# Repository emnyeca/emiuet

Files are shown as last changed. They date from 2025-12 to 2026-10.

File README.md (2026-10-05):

# Emiuet (EUB-04)

<p align="center">
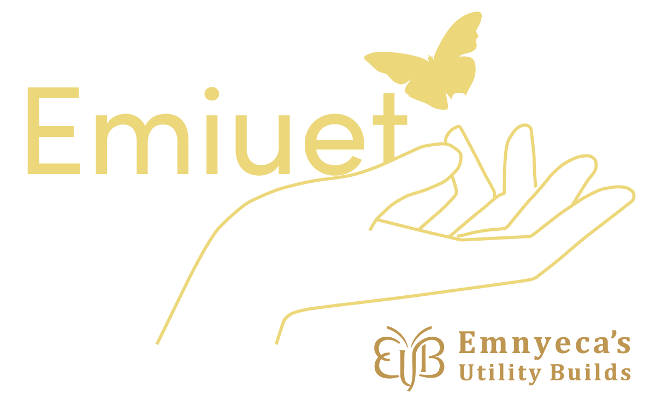
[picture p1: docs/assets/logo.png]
Emiuet logo
  
</p>

Fretboard-style MIDI instrument for guitarists.

## What Emiuet is

**Emiuet** is a 6 × 13 fretboard MIDI controller built around the way guitarists
think: strings, fret positions, chord shapes, voicings, and controlled expressive
gestures. It is not intended to become a general-purpose pad controller or a
piano-style keyboard.

The thirteen positions preserve familiar guitar-derived voicings without forcing
octave shifts or omissions. Expressive controls are deliberately constrained so
that performance remains predictable: Pitch Bend is upward-only, and the optional
MPE-style mode separates strings by MIDI channel rather than attempting a fully
general per-note control system.

Emiuet is part of **Emnyeca's Utility Build Series (EUB)**. The project prioritizes
musical intent, reliability, and a clear physical mental model over feature breadth.

## Playing surface and controls

- 6 strings × 13 positions: 78 low-profile keys
- Three sliders: Velocity, CC#1 Modulation, and upward-only Pitch Bend
- Constrained stringwise MPE-style performance mode
- Minimal OLED feedback designed to avoid distracting from performance
- USB MIDI, Type-A TRS MIDI OUT/IN, and BLE capability
- Auxiliary USB HID Keyboard mode (`TYPE`)
- One RGB LED under each key for fretboard visualization

`TYPE` is a desk-convenience feature for short text, navigation, and shortcuts.
It reuses the physical matrix but does not change Emiuet's identity as a musical
instrument. See [USB HID Keyboard Mode](docs/keyboard-mode.md) for the complete
layout and Fn layer.

## Rev.B hardware summary

Rev.B simplifies Emiuet into a USB-powered Device/UFP:

- ESP32-S3-MINI-1 using native USB
- One USB-C port for 5 V power, USB MIDI, USB HID, and firmware flashing
- Persistent USB MIDI + HID Keyboard composite device
- USB-C CC pull-downs with a comparator that tracks the Source current advertisement
- No USB Host, DRP, Host VBUS sourcing, internal battery, charger, or PowerPath
- SK6812 MINI-E ×78 on one data chain with a 3.3 V-to-5 V buffer
- Firmware-limited LED brightness/current based on conservative USB power budgets

Mobile use is supported with an external USB power bank. A 3 A Source advertisement
does not raise Emiuet's internal design ceiling above approximately 5 V / 1.5 A.

## MIDI and RGB behavior

Performance logic remains independent of individual transports. MIDI generation
must not block on USB, TRS, or BLE output. Incoming USB or TRS Note On/Off messages
can drive fretboard visualization through a transport-independent LED state layer.

The external protocol for device-level LED settings such as global brightness is
not defined yet. Standard musical Control Change messages are not repurposed for
device configuration; a future explicit protocol may use SysEx.

## Hardware and firmware sources

- Current Rev.B schematic draft: `hardware/kicad/Emiuet.kicad_sch`
- Historical Rev.A schematic: `hardware/kicad/Emiuet_RevA.kicad_sch`
- Rev.B GPIO allocation: `docs/pinout-v3.md`
- Current design decisions: `docs/decisions.md`
- Firmware: ESP-IDF 5.3.4 + FreeRTOS; OLED rendering uses u8g2

The checked-in PCB layout is historical Rev.A data and was not updated with the
Rev.B schematic. Rev.B placement and routing require a separate PCB redesign.

## Project status

The Rev.B schematic is an early architecture draft, not a fabrication-ready release.
USB-C current detection, reset/boot, the RGB buffer, and the OLED connector are
drawn; power and MIDI circuits are incomplete, and the matrix, sliders, buttons,
and protection circuits still need implementation. Component selection, footprints, PCB layout,
and physical validation remain open engineering work.

## License

To be determined. An open-source-friendly license is planned after prototype
validation.

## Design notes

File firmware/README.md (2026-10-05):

# Emiuet Rev.B firmware

ESP-IDF 5.3.4、ESP32-S3-MINI-1-N4R2向けです。

## Data paths

```text
matrix → input_router → USB/TRS MIDI TX or USB HID
USB MIDI RX / isolated TRS MIDI RX → midi_input → led_control
→ led_renderer → espressif/led_strip RMT DMA → SK6812 x78
CC comparator (GPIO37) → usb_cc_detect → usb_power → renderer current limiter / OLED status
```

USBはbus-powered Composite Deviceです。self-powered VBUS GPIO、Host stack、role
negotiation、battery/charger stateはありません。

初期RGB inputはMIDI Note On/OffとCC123 All Notes Offです。global brightnessを含む
device-level LED control protocolは未確定です。CC7などのstandard musical CCを
device configurationへ転用せず、将来SysEx等の明示的なprotocolとして定義します。
SysEx拡張点はtransportの外側に残していますが、protocolはまだ固定しません。

## Build

ESP-IDF shellで次を実行します。

```text
idf.py -B build-revb -D SDKCONFIG=build-revb/sdkconfig \
  -D SDKCONFIG_DEFAULTS="sdkconfig.defaults;sdkconfig.rev-b.defaults" build
```

FreeRTOS tickは1000 Hz（`CONFIG_FREERTOS_HZ=1000`）を前提にしています。100 Hzでは `pdMS_TO_TICKS(1)` と `pdMS_TO_TICKS(5)` が0になり、matrix scanは最小1 tick補正で10 ms周期、補正のない再送待ちは待機なしになっていたためです。既存のbuild用sdkconfigはdefaultsで上書きされないので、古い値のままだと `matrix_scan.c` がbuildを止めます。その場合はbuild directoryの `sdkconfig` の該当行を直すか、`sdkconfig` を退避して再生成してください。

MIDI送信task（USB/TRS/BLE）は、producerからのtask notificationで起きて、queueとcoalesce値を出し切ってから待ちます。演奏側は待ちなしでenqueueし、通知するだけです。

`espressif/led_strip`はRMT backendとESP32-S3 DMAを使用します。`sdkconfig.defaults`の
Default/1.5A LED budgetとbrightness ceilingはVAL-CORE-01/V3実測後に確定します。

Host-side logic testsは `tests/` にあります。ESP-IDF buildがUSB descriptor、I2C、
UART、RMTを含むintegration checkです。

## Rev.B設計中の電力制御

起動直後のCC判定前はRGB budgetを0にします。Default広告ではUSB configuredかつ非suspendの場合だけ200 mA設定を許可し、Rp ≥ 1.5 A（3 Aを含む）では1000 mA設定を上限とします。これはLEDの推定予算であり、基板全体のUSB消費電流保証ではありません。

`usb_cc_detect` は10 ms周期でGPIO37を読み、Rp低下は2 sample、上昇は100 ms安定で反映します。Type-C tSinkAdj（60 ms）内に収める設計ですが、実機の応答時間測定は未完了です。根拠・次の作業は [回路ノート](../docs/rev-b-circuit-notes.md) と [ロードマップ](../docs/rev-b-roadmap.md) を参照してください。

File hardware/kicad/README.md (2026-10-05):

# KiCad sourceの位置づけ

- `Emiuet.kicad_sch`: 現行Rev.B schematic architecture draft（KiCad 10形式）
- `Emiuet_RevA.kicad_sch`: Rev.A historical schematic
- `Emiuet.kicad_pcb`: Rev.A historical PCB layout。今回のRev.B作業では未変更

Rev.B schematicとRev.A PCBはconnectivityが一致しません。historical boardに対してschematicからPCB updateを実行しないでください。Rev.B placement/routingは別のPCB redesignとして行います。

Rev.B draftではsingle USB-C UFP/power path、CC Rd＋comparatorによる電流広告検出、ESP32-S3 GPIO nets、3.3 V regulator候補、RGB level shifter、78-pixel serpentine data chain、bulk/local bypass方針、TRS MIDI IN/OUT、OLED connector、matrix/UI busesを確認できます。

これはproduction releaseではありません。reset/BOOT、CC検出、RGB bufferの電源接続とidle bias、OLED connectorを実回路化しました。regulatorとMIDI interfaceは未接続で、matrix/slider/button、input protection、各LEDのlocal bypass等は実回路化が必要です。component selection、footprints、接続設計、ERC確認と実機Validationを経て確定します。

OLED footprint `Eminuet Library:Waveshare_OLED_0.96in_C_7P` はRev.A PCBのBrd2（`EUB_SSD1306:9E6018AD`、B面・180°配置）から形状を変えずに書き出したものです。旧名・説明のAdafruit 1.3 inchは実物と異なります。

初期の実ファイル検証と再設計・EDA評価の記録は [Rev.B監査](../../docs/rev-b-audit.md) にあります（監査時点の状態）。

現在の進捗・再開手順は [ロードマップ](../../docs/rev-b-roadmap.md)、追加回路の根拠と機構条件は [回路ノート](../../docs/rev-b-circuit-notes.md) にあります。`python tools/verify_hardware.py` をリポジトリrootから実行すると、KiCad 10.0.3でERC/netlist/BOM/SVGと入力hashを `build/hardware/` に出力します。違反が残る現状では終了コード1が正常な検出結果です。出力BOMはレビュー用で、発注用ではありません。

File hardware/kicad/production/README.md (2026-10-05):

# Rev.A historical production outputs

このdirectoryと既存の`Emiuet.kicad_pcb`はRev.A/historical design stateに属します。BQ24074、internal battery、boost、PowerPath、dual USB、Host VBUSの記述は現行Rev.B requirementではありません。

Rev.B schematicからこれらのoutputを再生成しないでください。schematic review後にRev.B用のplacement/routingを別工程として行い、production outputsを作り直します。

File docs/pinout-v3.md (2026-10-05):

# Emiuet Rev.B GPIO allocation

この表がRev.B schematicとfirmwareのGPIO正本です。ESP32-S3-MINI-1-N4R2を前提とし、
GPIO26は内蔵PSRAM用として使いません。

| Function | GPIO | Module pin | Reason |
|---|---:|---:|---|
| Slider PB / MOD / VEL | 1 / 2 / 4 | 5 / 6 / 8 | ADC1 CH0/1/3。USBやradioと競合しにくい連続群 |
| Matrix rows 0–5 | 5–10 | 9–14 | 6本連続でstring方向をescapeしやすい |
| Matrix cols 0–7 | 11–18 | 15–22 | 8本連続 |
| USB D- / D+ | 19 / 20 | 23 / 24 | native USB固定 |
| Matrix col 8 | 21 | 25 | USB pair直後の残り1本 |
| Matrix cols 9–12 | 33–36 | 28 / 29 / 31 / 32 | 4本連続。使用module variantでavailabilityを再確認 |
| USB_CC_1A5_N | 37 | 33 | CC comparatorのopen-drain出力（Low = Rp ≥ 1.5 A）、外部pull-up |
| SK6812 DATA | 38 | 34 | RMT TX → AHCT buffer |
| I2C SDA / SCL | 39 / 40 | 35 / 36 | OLED (0x3C) |
| SW CENTER / RIGHT | 41 / 42 | 37 / 38 | active-low button inputs |
| TRS MIDI OUT / IN | 43 / 44 | 39 / 40 | UART1 TX/RXをGPIO matrixで割当 |
| SW LEFT | 47 | 27 | active-low button input |
| Pilot LED | 48 | 30 | status output |

## Reserved and spare

| GPIO | Treatment |
|---:|---|
| 0 | BOOT/download button専用。通常機能へ共用しない |
| 3 | strapping。spare test pad候補だがreset中は外部駆動禁止 |
| 26 | N4R2 embedded PSRAM。使用禁止 |
| 45 / 46 | strapping。spare test pad候補だが量産機能へ割当しない |

GPIO3/45/46は「空き」ではありますが、安全な汎用spareとは扱いません。GPIO0を含む
4本はboot/recoveryを優先します。GPIO19/20にはLED、UART、matrixを重ねません。

## Routing intent

行列は5–18、21、33–36へまとめ、MCUからkey fieldへ束として出します。USB pairは
19/20からconnectorへ最短・等長で配線し、matrixから離します。ADC1の1/2/4は
slider RC filterへ短く配線します。RGB dataは38からbuffer、series resistor、D1へ
進み、5V power returnとは平行長距離にしません。UART43/44はTRS edge側へ一組で出します。

旧GPIO表、BAT_VSENSE、CHG、PGOOD、GPIO42 VBUS monitorはRev.A/撤回案です。

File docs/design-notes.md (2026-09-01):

# Emiuet – Design Notes

This document records design rationale, constraints, and implementation intent
that are intentionally omitted from the README.

It exists to preserve musical and engineering intent across revisions,
contributors, and AI-assisted development.

This is not a user manual.

---

## 1. Overall System Intent

Emiuet is designed as a performance instrument, not a development board.

Design decisions prioritize:
- Stable behavior during live performance
- Predictable response over feature completeness
- Musical intent over configurability

Some constraints may appear arbitrary from a purely technical perspective.
They are not.

---

## 2. Power System Design Rationale

### 2.1 Why a Power-Path Architecture

Emiuet assumes that:
- External USB power is not always clean or reliable
- The instrument may be used while charging
- Power transitions must not affect musical output

For these reasons, a power-path architecture is used so that
system operation and battery charging are decoupled.

### 2.2 Battery-First Thinking

The system is designed to operate as a battery-powered instrument first.

USB power is treated as:
- A charging source
- A temporary external supply

It is not assumed to be a stable system reference.

### 2.3 Standalone Product Boundary

Power conversion, charging, battery monitoring, and the rails required for
performance are part of Emiuet itself. Hearth may be useful as an independent
bench source or comparison design during validation, but Emiuet must neither
require Hearth nor assume EUB-BUS is present in normal operation.

Before Rev.B integration, the Emiuet power block is validated separately and
then exercised again with the MCU and I/O load. Passing a test with Hearth
alone is not evidence that Emiuet's internal power implementation has passed.

---

## 3. Startup Stability and Boot Safety

Stable startup behavior is considered a design requirement, not an implementation detail.

Certain MCU pins affect boot configuration and are intentionally excluded
from dynamic input or scanning roles.

The MCU's EN (Enable) pin requires an external RC delay circuit
to guarantee stable power-on sequencing.
This is a critical electrical requirement and is not optional.

Startup instability is treated as a hardware design issue rather than
something to be compensated for in software.

---

## 4. Input System and Noise Considerations

### 4.1 Key Matrix Philosophy

The key matrix is optimized for:
- Consistent scanning latency
- Predictable debounce behavior
- Minimal interaction with boot-sensitive pins

Matrix complexity is accepted in exchange for input reliability.

### 4.2 Slider Inputs and Noise Reality

Analog inputs are assumed to be noisy.

Both hardware-level and firmware-level mitigation are applied,
with the goal of achieving repeatable musical gestures rather than raw resolution.

---

## 5. Pitch Bend

### 5.1 Pitch Bend as a Musical Constraint

Pitch bend behavior in Emiuet is intentionally constrained.

- Direction is limited
- Range is fixed
- Behavior is predictable and repeatable

This limitation is not technical.
It is musical.

The design favors controlled expressive gestures similar to guitar bending,
rather than symmetrical or configurable pitch modulation.

Pitch bend stability relies on reliable return-to-center behavior.
This includes explicit reset logic and noise mitigation
to ensure repeatable expressive gestures.

### 5.2 MPE Mode as a Guitar-Oriented Constraint

Emiuet includes an optional MPE-style mode,
designed to support string-specific expression.

This mode is intentionally constrained.

While each string operates on its own MIDI channel,
pitch bend behavior remains direction-limited and range-fixed.

Pitch bend is applied only to the most recently active string,
reflecting the physical reality of guitar bending,
where expression is localized rather than globally distributed.

This is not a full implementation of generalized MPE.
It is a guitar-oriented reinterpretation of MPE concepts.

## 5.3. MPE Mode and Localized Pitch Expression

In MPE mode, each string (row) operates on its own MIDI channel.

Pitch bend is intentionally applied only to the most recently active string.
This behavior is a core part of the performance logic, not a side effect.

It reflects the physical reality of guitar playing,
where pitch expression is localized to a single string
rather than distributed across all sounding notes.

This rule defines how expressive gestures are interpreted by the instrument
and must be preserved to maintain predictable, guitar-like behavior.

---

## 6. Display

### 6.1 Display Strategy and OLED Usage

The OLED display is not intended to be a primary UI.

Its role is:
- Performance feedback
- State confirmation
- Minimal visual distraction

Display complexity is intentionally capped.
If information is not required during performance, it is not displayed.

The firmware assumes a specific graphics library to ensure consistent
timing and rendering behavior.

## 6.2 Display Constraints and Rendering Assumptions

The OLED display is intentionally limited both by design policy
and by technical constraints.

Rendering is based on the u8g2 graphics library,
which is assumed by the firmware.

Given rendering performance and memory constraints,
the display is limited to:
- Key press visualization
- Octave shift condition
- Basic system state confirmation (e.g., power or battery state)

The display is not intended to support dense UI elements or menus,
as this would interfere with performance timing and visual focus.

---

## 7. Firmware Structure (High-Level)

The firmware is structured so that:
- Input scanning cannot be blocked by rendering or communication
- MIDI output timing remains consistent under load
- UI updates are isolated from musical logic

Real-time behavior is prioritized over architectural elegance.

### 7.x MIDI Output (Non-Blocking + Coalescing)

As a musical instrument, Emiuet prioritizes stable, low-latency MIDI output.
However, the input/musical logic (matrix scan / slider / MPE) must never block on I/O.

Implementation intent:
- Each transport (TRS UART / USB / BLE) has a dedicated sender task and a discrete-event queue.
- `midi_out_send_*()` must return immediately; it only enqueues.
- Continuous controls are coalesced to prevent queue saturation:
	- Pitch Bend: latest value wins (per MIDI channel)
	- CC#1 (Modulation): latest value wins (per MIDI channel)
- Output realtime priority among transports is TRS > USB = BLE.
	Simultaneous output is allowed.

---

## 7.1 USB Device Bring-up Note (DevKit vs Prototype)

Some ESP32-S3 DevKits expose *two different* USB paths:

- USB-Serial/JTAG (debug/programming) port
- Native USB peripheral port (D+/D- on GPIO20/GPIO19)

If the cable is connected to the USB-Serial/JTAG port, the TinyUSB Device stack can be fully initialized in firmware yet **Windows will not enumerate the Emiuet composite device**, and `tud_mount_cb()` / `tud_mounted()` will never trigger.

TODO (when the Emiuet prototype PCB arrives):
- Verify the cable is connected to the native USB Device port wired to GPIO20/GPIO19 (see pinout-v3).
- If Windows still enumerates only Serial/JTAG, temporarily disable USB-Serial/JTAG in `menuconfig` so TinyUSB can own D+/D-.
- Confirm composite enumeration first (Device Manager / MIDI and HID listings) before debugging event flow.

---

## 8. Things That Look Flexible but Are Not

The following aspects may appear configurable but are intentionally fixed:

- Pitch bend direction and range
- Absence of DIN MIDI output
- TRS MIDI (Type-A) output requirements
- Display information density
- Assumptions about USB power quality

TRS MIDI (Type-A) output must use a dedicated 5V current loop circuit,
compliant with MIDI specifications, and must not be driven directly
by 3.3V logic.

These constraints are considered part of the instrument’s identity.

---

## 9. Where Changes Are Acceptable

The following areas are considered safe for experimentation:

- Visual design and enclosure materials
- Non-performance-critical UI elements
- Firmware refactoring that preserves observable behavior

Any change affecting musical response or power stability
should be evaluated with caution.

---

End of design notes.

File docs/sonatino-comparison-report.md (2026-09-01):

# Sonatino / Emiuet 比較技術レポート

作成日: 2026-08-26  
対象: Sonatino `3dd28dbe` / Emiuet `6cb9148b`

## 1. 結論

Sonatino は、Emiuet の完成形を直接示す設計ではない。Sonatino は小型の ESP32-S3 オーディオ開発ボードであり、Emiuet はギタリスト向けの大型 MIDI 演奏装置である。中心となるユーザー体験も、主要な信号も、基板形状も大きく異なる。

一方で、次の領域はEmiuetにとって有用な参照になる。

1. ESP32-S3、USB-C、Li-ion電源を同居させる際の回路ブロック構成
2. デジタル系とアナログ系の電源・GND・デカップリングの考え方
3. USB、電源、MCU、外部I/Oを小さな領域へまとめる部品配置
4. 起動・リセット・ストラッピング・テストポイントの扱い
5. 回路図上に計算根拠、設計意図、DNP候補を残す記述方法
6. 部品の供給終了やライセンスを設計リスクとして明示する姿勢

最も重要なのは、Sonatino の回路を移植することではなく、**Emiuet の制御基板領域をレビューするための比較基準として使うこと**である。

Emiuet は、電源の目的適合性、USBの役割分離、演奏入力、MIDIファームウェア、製造出力の点では、すでにSonatinoよりEmiuetの目的に合った固有設計を持つ。ここをSonatinoへ寄せるべきではない。

## 2. 調査範囲と前提

### Sonatino

- `README.md`
- `LICENSE.txt`
- `schematic.pdf` 全3ページ
- `kicad_project/Sonatino.kicad_sch`
- `kicad_project/USB_Power.kicad_sch`
- `kicad_project/Audio.kicad_sch`
- `kicad_project/Sonatino.kicad_pcb`
- `assets/sonatino-pcb.jpg`

### Emiuet

- `README.md`
- `docs/decisions.md`
- `docs/design-notes.md`
- `docs/pinout-v3.md`
- `docs/BLE/`
- `hardware/kicad/Emiuet.kicad_sch`
- `hardware/kicad/Emiuet.kicad_pcb`
- `hardware/kicad/production/`
- `firmware/main/`
- `firmware/sdkconfig.defaults`

本レポートはリポジトリ内の設計データを比較したものである。Sonatino の回路図PDFは全ページを画像化して確認した。KiCad CLIが環境にないため、両基板の最新ERC/DRCを新規実行した結果ではない。また、実機測定、熱解析、USBコンプライアンステスト、RF評価は含まない。

## 3. 製品としての主従関係

| 観点 | Sonatino | Emiuet |
|---|---|---|
| 主目的 | ESP32-S3による音声処理・開発 | ギタリスト向け演奏用MIDIコントローラー |
| 中心体験 | 音声入出力とDSP実験 | 6弦×13フレット、コード、弦単位表現 |
| 製品性格 | 汎用開発ボード | 意図的に制約された楽器 |
| 主要入力 | マイク、ライン、microSD、GPIO | 78キー、3スライダー、3ボタン |
| 主要出力 | ライン、ヘッドホン、スピーカー、GPIO | USB-MIDI、TRS MIDI、BLE-MIDI |
| UI | 最小限のボタン、LED、DIP | OLED、状態LED、演奏モード操作 |

この違いから、Sonatino のオーディオ回路や拡張ヘッダーをEmiuetへ追加することは、参考利用ではなく製品目的の変更になる。参照範囲は共通基盤技術に限定すべきである。

## 4. ハードウェア比較

### 4.1 全体仕様

| 項目 | Sonatino | Emiuet | 評価 |
|---|---|---|---|
| MCU | ESP32-S3-WROOM-1U、16MB Flash、8MB PSRAM | ESP32-S3-MINI-1 | 同じMCU系列だがモジュールと要求が異なる |
| 無線 | Wi-Fi、BLE 5.0 LE | BLE-MIDIおよび専用アプリ接続を計画 | 無線機能は共通、用途は異なる |
| USB | USB-C 1ポート、給電・プログラム・USBデータ | 充電専用と固定USB Device/UFPの2ポート | Emiuetの役割分離を維持すべき |
| 電池 | 1セル、TP4056とディスクリート回路 | 1セル、BQ24074 power-path | Emiuetの方が演奏中給電の目的に適合 |
| 3.3V | デジタル用とAVDD用にNCP167を分離 | AP7333とアナログ配慮、別途5V昇圧 | Sonatinoの電源分離はレビュー材料になる |
| USB保護 | SRV05-4、CCのRd | Rev.AはTPD2EUSB30、コモンモードチョーク、ヒューズ、TUSB320 | Rev.Bでは固定UFP化して役割回路を簡略化する |
| 基板層 | 4層 | 2層 | 直接模倣不可。信号帰路の比較基準になる |
| 外形 | 約65×30mm | 約297×102.4mm | 配線密度とコスト条件が大きく異なる |
| 板厚・表面 | 1.6mm、ENIG | 1.6mm、ENIG | 共通 |
| GND | GND/GNDA、0Ω接続点あり | GNDD/GNDA | 接続位置と帰路の再確認が重要 |
| 製造データ | KiCadソース中心 | BOM、座標、IPC netlist、製造ZIPあり | Emiuetの方が製造引き渡しに近い |

### 4.2 MCU、起動、書き込み

共通点はESP32-S3とネイティブUSB D-/D+の利用である。SonatinoではESP32-S3-WROOM-1Uを使い、BOOTボタン、RESETボタン、ENのRC、MCLKテストポイントを回路図上で明確に区切っている。GPIO0が起動時ストラッピング対象であることも注記されている。

EmiuetではGPIO45/GPIO46をキーマトリクス列に使うため、起動後300ms待機し、行入力、列出力の順に有効化し、さらに初回5スキャンを破棄する実装がある。この処理はEmiuet固有の起動安全策であり、Sonatinoより踏み込んでいる。

Emiuetに活かせる点は次の通り。

- 回路図上でBOOT、RESET、EN、書き込み経路を一つのブロックとして見せる
- 起動時に影響する信号へ、回路図上の注記とファームウェア上の保護を両方置く
- GND、EN/RESET、BOOT、3.3V、5V、USB D+/D-へ、プローブしやすいテストポイントを用意する

EmiuetにはTP1/TP3/TP4/TP5があるが、製造BOM・座標データでは通常部品として現れない。これはSMDテストパッドであれば正常だが、基板レビュー時には各TPのネット名と実機でのアクセス方向を明示したテスト表が必要である。

### 4.3 USB-C

SonatinoのUSB-Cは、5.1kΩのCC抵抗を持つシンプルなUSBデバイス/シンク構成である。単一ポートでプログラミング、通信、給電を兼ねるため、回路の見通しがよい。

この比較を作成した時点のRev.Aでは、充電専用ポートとUSB-MIDI/DRP
ポートを分け、TUSB320で役割を扱う前提だった。このDRP/OTG前提は
Rev.Bの正式仕様では廃止された。Rev.Bは充電専用USB-C #1と、固定USB
Device/UFPのUSB-C #2を分離したまま、CC1/CC2をRdで固定する。

ESD、必要な信号フィルタ、VBUS保護・検出はUSB roleとは別の安全要件
なので維持または実測評価する。

Sonatinoから取り込む価値があるのは、USBセクションを回路図上で独立させ、CC、VBUS、D+/D-、ESD、電源切替の関係を一画面で追える構成である。

Emiuetでは次を次回基板前に確認するべきである。

1. USB-MIDI側D+/D-の差動ペアが、層変更やGND分断をまたがず連続した帰路を持つこと
2. ESD素子、コモンモードチョーク、MCUの順序と距離
3. 2ポート間のVBUS逆流防止と、片側または両側を同時接続した状態
4. 固定UFPのCC抵抗と、自己給電Device用VBUS検出の対応
5. ネイティブUSBとUSB-Serial/JTAGを混同しない書き込み・検証手順

### 4.4 電源、充電、バッテリー

SonatinoはTP4056、MOSFET、ダイオード、DW01系保護を組み合わせた比較的単純な1セル電源である。回路図には逆漏れへの対策、充電電流、逆極性保護、バッテリー分圧の計算が直接記載されている。バッテリー最大4.2Vを約3.18Vへ落とし、分圧損失を約6.8µAとする説明もある。

Rev.AのEmiuetはBQ24074によるpower-path、TPS61023による5V生成、AP7333による3.3V生成に加え、LM66100で内部5VをUSB-C #2 VBUSへ送る経路を持つ。Rev.Bでは前者の製品電源要件を維持して検証する一方、Device-only方針によりLM66100のUSB-C #2出力経路は削除対象である。Host用経路と「演奏しながら充電する」ための内部power-pathを同一視してはならない。

したがって、SonatinoのTP4056電源回路への置換は推奨しない。取り込むべきなのは次の設計表現である。

- 分圧比、待機電流、充電電流、電圧上限を回路図の近くに書く
- USBのみ、電池のみ、両方接続、電源OFFの各電流経路をレビューする
- 逆接、逆流、保護IC動作時の状態を明示する
- 重要な電源レールへテストポイントを置く

Emiuetの回路データでは、TPS61023のシンボルメタデータに明確な不整合がある。値は`TPS61023DRLR`だが、DatasheetがTPS62A02を指し、Descriptionも降圧コンバーターになっている。実回路の部品値、ピン番号、フットプリントが正しくても、レビュー時に誤判断を誘発するため修正対象である。

### 4.5 アナログ、GND、ノイズ

SonatinoはADC、DAC、マイクプリアンプ、ヘッドホンアンプ、スピーカーアンプを持つため、アナログ品質への要求が高い。AVDD専用LDO、GNDA、フェライトビーズ、ローパスフィルター、各IC直近のデカップリングが設計の中心にある。GNDとGNDAはR33の0Ωで接続され、接続位置を回路として明示している。

Emiuetには音声回路はないが、3本のスライダーとBAT_VSENSEがある。これらは演奏表現に直結するため、分解能より再現性とノイズ耐性が重要である。

Emiuetへの適用方針は次の通り。

- SonatinoのAVDD専用LDOをそのまま追加するのではなく、まず現在のRC、デカップリング、GNDA/GNDD接続、ADCサンプリングを測定する
- 昇圧回路、LED/PWM、キーマトリクス列、USB D+/D-からADC配線を離す
- GNDA/GNDDを分ける場合、信号の帰路が分断を横断しないことを確認する
- スライダー端、MCU ADC端、BAT_VSENSEでノイズと応答を測り、ハードウェアRCとファームウェアEMAの役割を分ける

SonatinoのGND分割は参考になるが、分割そのものが正解ではない。2層で横長のEmiuetでは、分割面が高速信号や入力線の帰路を切る危険があるため、接続点と電流経路で判断する必要がある。

### 4.6 PCB構成と実装密度

Sonatinoは約65×30mmの4層基板で、信号層2層と内層電源2層を持つ。部品はコネクタの周辺とMCU/音声ICの近傍に密集し、四隅に固定穴を置く。小さな混載基板として、電源帰路、デカップリング、USB差動配線、音声クロック配線をまとめやすい構成である。

Emiuetは約297×102.4mmの2層基板であり、大部分は78キーの規則的なマトリクスである。電子回路は端部に集約され、別のトップ左右基板とプレート基板も持つ。この構造は楽器の形状と演奏性から生じており、Sonatinoの小型化を目標にすべきではない。

活用方法は以下が妥当である。

- Emiuet全体を4層化するのではなく、USB・電源・MCUが集まる領域の配置と帰路をSonatino並みの密度でレビューする
- 2層でUSB、昇圧、ADCの共存が難しいことが測定で判明した場合に限り、4層化または制御部の小基板化を比較案にする
- キーマトリクス領域はEmiuet固有の低速・大面積設計として扱い、高速/アナログ領域とレビュー基準を分ける

## 5. ファームウェアと機能実装

### 5.1 Sonatino側

今回クローンしたSonatinoリポジトリにはファームウェアがない。READMEから別のExamplesリポジトリへ案内されるが、本比較の対象には含めていない。そのため、リアルタイム処理、USB、BLE、電源状態管理について、Sonatinoをファームウェア実装の参照にはできない。

### 5.2 Emiuet側

Emiuetには次の実装がある。

- 6×13キーマトリクスの走査とデバウンス
- ストラッピングピン保護の遅延初期化
- ノート生成と弦単位チャンネル割り当て
- 上方向専用ピッチベンドとStringwise Bend
- USB-MIDIのTinyUSB実装
- TRS MIDIの31250bps UART実装
- USB/TRS/BLEごとの非同期キュー
- Pitch BendとCC#1のチャンネル別coalescing
- ADC管理、スライダー平滑化、OLED、LED、電源状態表示

これはSonatinoにはない、Emiuetの中核的な資産である。

ただし、実装済みと設計済みを分ける必要がある。

| 項目 | 状態 |
|---|---|
| USB-MIDI | 実装あり。実機でのネイティブUSB列挙確認が残る |
| TRS MIDI | 実装あり。UART0コンソール競合を避ける設定が必要 |
| BLE-MIDI | キュー形状のみ。低レベル送信は成功扱いするstub |
| BLEペアリング | weak stub |
| Telemetry/Control/OTA | 仕様文書あり。実装は確認できない |
| OLED | 実装あり。ただし関数名やログに`demo`が残る |
| 自動テスト | Emiuet固有のテスト群は確認できない |

ファームウェアに関する優先課題は、Sonatinoからコードを借りることではなく、現在の実装状態を人間が誤認しない形にすることである。

- `firmware/README.md`がESP-IDFのHello Worldテンプレートのままなので、実際のビルド、書き込み、設定、検証手順へ更新する
- BLEを「設計済み」と「実装済み」に分け、stubを通常ルートで有効にしない
- `oled_demo_start()`など、製品機能になったdemo命名を整理する
- USB列挙、TRS送信、キーマトリクス、ピッチベンド復帰を保護する最小限の試験を置く

なお、`board_pins.h`のADCコメントはGPIO1/2のチャンネル番号を実装値より1つ大きく説明している一方、マクロはGPIO1→CH0、GPIO2→CH1、GPIO4→CH3になっている。実装とコメントのどちらを正とするかではなく、ESP32-S3のデータシートとESP-IDF定義で再確認し、コメントを一致させるべきである。

## 6. 文書、ライセンス、保守性

SonatinoはCERN-OHL-P-2.0を明示し、OSHWA認証番号、商標、文書の扱い、WM8782の供給終了をREADMEで説明している。設計の再利用可能性と、再利用してはいけない名称・文書の境界が比較的明確である。

Emiuetは設計思想、禁止事項、音楽的な判断をSonatinoより詳しく記録している。一方で、ライセンスは未決定である。

Sonatinoの回路断片をEmiuetへ実際に移植する場合は、少なくとも次を行う必要がある。

- コピー元、対象回路、取得コミット、変更内容、変更日を記録する
- Sonatinoの名称やロゴをEmiuetの製品表示へ流用しない
- CERN-OHL-PのNotice要件を確認し、必要な表示を保持する
- Emiuet自身のハードウェア/ファームウェア/文書ライセンスを公開前に決める

これは法的助言ではない。公開・販売前には採用部分と配布形態に応じた最終確認が必要である。

## 7. Emiuetへ活かす優先順位

### 優先度A: 次回PCB製造前

1. **U1のモジュール/フットプリント照合**  
   BOM上の値はESP32-S3-MINI-1だが、フットプリント名は`ESP32-S2-MINI-1_thermalVia_noSilk`である。名称だけの流用か、実パッドも互換前提かを、公式推奨ランドパターンと照合する。

2. **TPS61023シンボルメタデータ修正**  
   誤ったデータシートと降圧説明を修正し、ピン番号、FB抵抗、インダクタ、出力コンデンサも正本データシートで確認する。

3. **USB-C 2ポートの状態表を作る**  
   電池のみ、充電USBのみ、MIDI USBのみ、両USB同時、電源OFFを行列化し、VBUS、SYS、5V、3.3V、逆流、列挙動作を確認する。

4. **GNDA/GNDDと高速信号帰路を確認する**  
   USB差動対、ADC入力、昇圧スイッチング電流、MIDI電流ループがGND境界を不適切に横断していないか確認する。

5. **ERC/DRC結果を製造スナップショットへ残す**  
   現在の製造ZIP、BOM、座標に加え、製造対象コミットに対応するERC/DRCの結果を保存する。

6. **実機測定項目を固定する**  
   USB切替時のリセット、3.3V/5V立上り、ADCノイズ、低電圧時動作、GPIO45/46押下起動、USB列挙、TRS MIDI波形を測る。

### 優先度B: 人間が監修しやすい設計へ

1. 回路図を、全体、USB/電源、MCU/UI、キーマトリクス程度の少数の階層へ整理する
2. 分圧、充電電流、昇圧出力、RC時定数を回路の近くへ記載する
3. テストポイント一覧をネット名、目的、正常値とともに1表へまとめる
4. BOMへ供給リスク、代替可否、正本データシートを持たせる
5. `firmware/README.md`を実装に一致させる
6. Sonatinoを実際に引用した場合だけ、第三者Noticeを追加する

### 優先度C: 測定結果が必要な選択肢

- 制御部だけの4層化または小基板化
- ADC用の独立アナログ電源
- USB/電源回路の追加シールドやフィルタ
- テスト治具用パッドの増設

これらはSonatinoに存在するという理由だけでは採用せず、Emiuet試作機のノイズ、EMI、実装歩留まり、コストから判断する。

## 8. 直接流用しないもの

- WM8524、WM8782、MAX98357A、TPA6132A2、MAX4467などの音声回路
- TRRSオーディオジャックとmicroSD
- 汎用GPIOヘッダー
- TP4056中心の充電構成
- 単一USB-Cポートへの統合
- WROOM-1Uへの変更
- Bluetooth Audio EditionのA2DP構成
- 4層基板という結論そのもの

これらはSonatinoの目的には合理的だが、Emiuetの楽器としての主目的、薄型化、既存のpower-path方針、MIDI出力方針を弱める。

## 9. EmiuetがSonatinoより先に進んでいる点

- 演奏中の安定性を明文化したpower-path方針
- 充電とUSB-MIDIの物理ポート分離
- 78キーの実楽器入力とMPE風の弦単位表現
- MIDI生成をI/Oから分離する非ブロッキング構造
- USB/TRS/BLEごとのキューと連続値coalescing
- ストラッピングピンを考慮した段階的初期化
- BOM、座標、IPC netlist、製造ZIPの保持
- 製品固有の判断と禁止事項を残した文書

したがって、比較の目的はEmiuetをSonatinoへ近づけることではない。Sonatinoの成熟した小型混載基板の作法を使って、Emiuet固有設計の弱点を早く見つけることである。

## 10. 最終評価

Sonatinoから最も価値高く得られるものは、オーディオ機能ではなく、**小型ESP32-S3混載基板における電源・USB・GND・デカップリング・テスト性の見せ方**である。

Emiuetは目的、入力方式、MIDI処理、電源要求の面で独自性が強く、主要アーキテクチャを変更する必要はない。特に電源はEmiuet内部に保持し、HearthやEUB-BUSを通常動作の前提にしない。次回基板前には、Sonatinoを比較基準として、U1フットプリント、TPS61023メタデータ、USB二重接続、GNDA/GNDD帰路、製造時ERC/DRCの5点を重点確認するのが最も効果的である。

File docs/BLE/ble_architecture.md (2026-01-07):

# BLE_ARCHITECTURE.md
# Emiuet BLE Architecture

This document defines the BLE architecture of Emiuet.
It is normative for firmware + app implementation.

## 0. Goals

Emiuet is a performance instrument.
BLE integration MUST NOT compromise musical stability.

Primary app integration goals (priority order):
1) OTA firmware update and configuration
2) Real-time performance GUI (key state + analysis on app)
3) Real-time harmony sharing: app -> Emiuet mapping updates (with future device-to-device sync)

## 1. Roles

- Emiuet is ALWAYS a BLE Peripheral.
- External devices (PC, iPhone, etc.) are BLE Centrals.

### Central roles (logical)
- MIDI Host Central:
  - Uses the BLE MIDI Service for MIDI I/O.
  - MUST be exclusive (only one MIDI Host Central at a time).
- App Central:
  - Uses Emiuet Custom Services (Telemetry / Control / DFU).
  - MUST be exclusive (only one App Central at a time).

## 2. Concurrent connections

### Policy
- Emiuet MUST support up to 2 concurrent Central connections:
  - 1 x MIDI Host Central
  - 1 x App Central

- Emiuet MUST NOT support multiple App Centrals concurrently.
- Emiuet MUST NOT allow App Central to access BLE MIDI characteristics.

Rationale:
- Protect stability and bandwidth for 60 Hz telemetry and musical I/O.

## 3. Services

Emiuet exposes the following services:

### 3.1 BLE MIDI Service (standard)
- Purpose: MIDI transport for DAW / PC / compatible hosts.
- Access: MIDI Host Central only.
- Concurrency: exclusive.
- Priority: musical transport priority aligns with existing policy:
  TRS > USB = BLE (simultaneous output allowed).

### 3.2 Telemetry Service (custom)
- Purpose: real-time performance state to App Central.
- Access: App Central only.
- Mode: Notify-only (primarily).
- Update:
  - Active: 60 Hz target (16.67 ms period)
  - Idle: reduced rate (default 10 Hz) or event-driven low rate
- Backpressure:
  - Telemetry MUST be "latest-wins".
  - Telemetry MUST NOT build unbounded queues.
  - If notifications are delayed, older frames MUST be dropped.

### 3.3 Control Service (custom)
- Purpose: app -> device control for configuration and real-time harmony context.
- Access: App Central only.
- Mode: Write (with response where required for correctness).
- Control commands MUST be transactional using epoch + COMMIT (see spec).

### 3.4 DFU/OTA Service (custom)
- Purpose: firmware update over BLE.
- Access: App Central only.
- Safety:
  - OTA MUST require explicit confirmation in the app.
  - During OTA mode, Emiuet MUST stop all performance functions:
    - Stop MIDI I/O
    - Stop Telemetry
    - Stop Control (except DFU)
  - After OTA completion, Emiuet MUST reboot into normal mode.

## 4. Advertising strategy

- Emiuet SHOULD advertise Custom Services in normal operation (Telemetry/Control).
- Emiuet MAY advertise BLE MIDI Service concurrently, but the implementation MUST enforce:
  - App Central cannot use BLE MIDI characteristics.
  - Only one MIDI Host Central is allowed.

Optional hardening:
- Emiuet MAY use a "MIDI connect window" concept:
  - Strongly advertise BLE MIDI only when no MIDI Host is connected
  - Or when user explicitly enables MIDI pairing mode
This is allowed if needed for stability across host OS behavior.

## 5. Timing and timestamps

Telemetry frames MUST include:
- A device-local monotonic timestamp (t_ms or t_us)
- A sequence counter (seq) for loss detection

Notes:
- The timestamp is NOT synchronized across devices by default.
- Future synchronized performance (Emiuet-to-Emiuet) will require a separate time sync mechanism.
- Keeping device-local timestamp now is REQUIRED to enable future sync designs.

## 6. Non-blocking policy alignment

The firmware transport policy applies to BLE:
- Musical generation / input scanning MUST NOT block on BLE I/O.
- BLE MIDI sending MUST be performed by a dedicated sender task/loop.
- Telemetry is "best-effort" and MUST yield to musical timing constraints.

## 7. Failure modes

- If App Central disconnects:
  - Emiuet MUST continue to operate as an instrument without degradation.
  - No musical logic may depend on app presence.

- If MIDI Host disconnects:
  - Emiuet SHOULD resume advertising availability for MIDI host connection.
  - No UI-heavy operations should run in tight loops due to disconnection.

End of document.

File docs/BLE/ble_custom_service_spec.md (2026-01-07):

# BLE_CUSTOM_SERVICE_SPEC.md
# Emiuet Custom BLE Services Specification

This document specifies custom services used by the Emiuet companion app.
It is normative for both firmware and app.

Conventions:
- MUST / MUST NOT / SHOULD are used in the RFC sense.
- All multibyte fields are little-endian unless stated otherwise.

## 1. Overview

Custom services are split by responsibility:

1) Telemetry Service
   - Device -> App, real-time status frames (60 Hz active)
2) Control Service
   - App -> Device, configuration + harmony context updates
3) DFU/OTA Service
   - App -> Device, firmware update (device stops all performance functions during OTA)

App Central is the only allowed client for these services.
Only one App Central connection is allowed concurrently.

## 2. Telemetry Service

### 2.1 Purpose
Provide a real-time view of performance state for GUI:
- key press visualization (6x13)
- mode indicators (octave, MPE, etc.)
- optional slider states (PB/Mod/Vel)
- allow app-side chord/harmony analysis

### 2.2 Characteristics
This spec uses placeholder UUID names. Replace with actual UUIDs later.

- TELEMETRY_FRAME (Notify)
  - Properties: Notify
  - CCCD: required

### 2.3 Frame rate policy
- Active mode: 60 Hz target.
- Idle mode: reduced rate (default 10 Hz) OR event-driven low rate.
- Transition rules:
  - Active mode SHOULD engage when key state changes or recent activity is detected.
  - Idle mode SHOULD engage after a quiet period (suggested 1.0 s, adjustable).

### 2.4 Backpressure policy
- Telemetry MUST be latest-wins.
- Firmware MUST NOT buffer more than 1 pending telemetry frame per connection.
- If BLE notify cannot send in time, older frames MUST be dropped.
- The app MUST tolerate missing frames and use `seq` to detect gaps.

### 2.5 Telemetry frame format (v1)
All fields are REQUIRED unless marked optional.

TelemetryFrameV1:
- u8  version        : 0x01
- u8  seq            : increments each emitted frame (wrap allowed)
- u32 t_ms           : monotonic device-local milliseconds since boot (wrap allowed)
- u8  octave         : signed offset encoded as two's complement (e.g. -2..+2 typical)
- u8  mode_flags     : bitfield (see below)
- u8  keys_len_bytes : MUST be 10 for v1 (78 bits packed)
- u8  keys_bitmap[10]: packed key state bits (LSB-first within each byte)
- [optional] sliders block:
  - u8  sliders_flags
  - u16 pb   (normalized)
  - u16 mod  (normalized)
  - u16 vel  (normalized)

Mode flags (mode_flags):
- bit0: MPE enabled
- bit1: reserved
- bit2: reserved
- bit3: reserved
- bit4..7: reserved for future

Keys bitmap packing:
- 78 keys are packed into 10 bytes (80 bits total).
- Bits 78..79 MUST be zero.
- The mapping of (string,row,col) to bit index MUST be defined in firmware + app consistently.
  Recommendation:
  - bit_index = row * 13 + col
  - row = 0..5 (String 1..6)
  - col = 0..12 (Fret 0..12)
If the physical mapping differs, define a mapping table in a dedicated doc.

### 2.6 App-side chord analysis
- The device MUST NOT compute chord names for Telemetry v1.
- The app SHOULD compute chord/harmony from keys_bitmap plus known tuning/mapping state.

## 3. Control Service

### 3.1 Purpose
Provide controlled, transactional updates from app to device:
- configuration changes
- harmony context updates for real-time key mapping

### 3.2 Characteristics
- CONTROL_CMD (Write / Write With Response depending on command)
- CONTROL_EVT (Notify) optional, for acknowledgements and state changes

### 3.3 Transaction model: epoch + COMMIT (REQUIRED)

Rationale:
- Prevent partial application and timing jitter.
- Enable future timed commits using timestamps (e.g., commit at a musical boundary).

Definitions:
- epoch: u16 or u32 chosen by firmware, increments per transaction
- staged state: data received but not yet applied to active performance state

Rules:
1) App sends one or more SET_* commands tagged with the same epoch.
2) Device stores them as "staged" under that epoch.
3) App sends COMMIT(epoch).
4) Device atomically swaps staged -> active for that epoch.

MUST requirements:
- Device MUST NOT apply staged changes before COMMIT for that epoch.
- Device MUST apply all staged changes atomically at COMMIT.
- If COMMIT is received for an unknown epoch, device MUST reject and optionally notify error.
- Device MUST discard stale staged epochs after a timeout (suggested 2 s) to avoid memory leak.

Default UX:
- App MAY send SET_* immediately followed by COMMIT to achieve "instant feel".
  This preserves the option for timed commits later.

### 3.4 Commands (v1 set)

Encoding (suggested):
- u8  version  : 0x01
- u8  cmd_id
- u16 epoch
- payload...

Command IDs (suggested):
- 0x01 SET_HARMONY_CONTEXT
- 0x02 COMMIT
- 0x03 SET_CONFIG_PARAM
- 0x04 REQUEST_DEVICE_INFO
- 0x05 ENTER_OTA_MODE

#### 3.4.1 SET_HARMONY_CONTEXT (cmd_id=0x01)
Goal: allow app to update mapping in a high-level way.

Payload (example):
- u8  root_note      : 0..11 (C..B)
- u8  scale_id       : enumerated
- u16 chord_id       : enumerated or bitmask-based
- u8  strategy_flags : mapping strategy options
- u8  reserved

Notes:
- The precise model can evolve. Keep it compact and versioned.

#### 3.4.2 COMMIT (cmd_id=0x02)
Payload:
- none (epoch is in header)

#### 3.4.3 SET_CONFIG_PARAM (cmd_id=0x03)
Payload:
- u16 param_id
- u8  value_type  : (u8,u16,i16,u32,i32,f32,bytes)
- value...

The device SHOULD expose a parameter table for forward compatibility.

#### 3.4.4 ENTER_OTA_MODE (cmd_id=0x05)
- MUST require app confirmation UX before sending.
- When accepted, device MUST:
  - stop all performance services and MIDI output
  - switch to OTA/DFU mode
  - notify state change if CONTROL_EVT exists

## 4. DFU/OTA Service

This document defines behavioral requirements, not the full DFU protocol.

### 4.1 OTA entry and exclusivity
- OTA MUST be initiated by App Central.
- OTA MUST require explicit in-app confirmation.
- During OTA:
  - BLE MIDI MUST be stopped
  - Telemetry MUST be stopped
  - Control MUST be stopped except for DFU operations

### 4.2 Post-OTA
- On success: device MUST reboot.
- On failure: device MUST provide a safe recovery path.
  - Minimum requirement: allow USB-based recovery in development.
  - Future requirement: robust A/B or bootloader strategy (out of scope here).

## 5. Versioning and compatibility

- Telemetry frames and control commands MUST include a version field.
- Breaking changes MUST bump version.
- Unknown fields SHOULD be ignored by the receiver where possible.

End of document.

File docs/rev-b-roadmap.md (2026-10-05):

# Rev.B 開発ロードマップ

最終更新: 2026-10-05。開発者・AI向けの進捗と再開地点の正本。Codex、Claude Codeなど、chatやAIを替えてもこの文書から再開する。

製品判断は [decisions.md](decisions.md)、GPIOは [pinout-v3.md](pinout-v3.md)、初期調査は [監査](rev-b-audit.md)、追加回路の根拠・残課題は [回路ノート](rev-b-circuit-notes.md)。仕様の正本を増やさない。

## 目指すところ

6×13の演奏体験とRev.Aの外観・操作部配置を維持し、USB給電専用のRev.Bを完成させる。KiCad上の実回路を小さな単位で設計し、接続検証・描画・独立レビュー・実測を重ねる。Rev.A保存のための大規模再編は行わない。

## 一目で見る進め方

| 順番 | 到達点 | AIの作業 | アムニェカさんの作業 | 状態 |
|---|---|---|---|---|
| 1 | 別のchat・AIから再開できる | ロードマップと共通入口を整備 | 同じ作業フォルダを開く | 完了 |
| 2 | 回路を編集・機械検証・目視確認できる | KiCad依存整理、ERC/netlist/BOM/SVG出力 | 図の読みやすさを監修 | 出力環境は完了、回路合格は未達 |
| 3 | USB給電条件と部品選定の根拠が揃う | 状態表、故障時FW、電源候補比較 | CC検出方式・OLED型番は回答済み | CC検出は設計済み、3.3 V・保護・電力内訳が未完 |
| 4 | 接続の揃ったRev.B schematic | MCU/USB/電源/MIDI/matrix/UI/RGBの設計と独立レビュー | tradeoffと回路を監修 | reset/BOOT・CC検出・OLED・RGB buffer済み、電源/MIDI/matrix/slider未完 |
| 5 | 小基板で電源・信号を実証 | 既存VAL-CORE-01の回路図を現行方針へ更新し、BOM・測定手順・レビュー材料を揃える | 回路と部品候補を監修し、発注・組立・V0–V2測定を判断 | VAL-CORE-01はTUSB320前提の旧案を含むため更新待ち |
| 6 | 外観を維持した78キーRev.B PCB | 機構照合・配置配線、DRC/parity/DFM | 組立性と発注を確認 | 小基板の結果待ち |
| 7 | 楽器として使えることを実証 | 測定結果の解析・修正 | 78キー負荷・演奏・連続運転のV3測定 | Rev.B試作待ち |

ERC合格、実機合格、製造承認は別々に記録する。実測前はUNVERIFIED。

## 現在の再開地点

**次は手順3の3.3 V regulator・入力保護・Default電力内訳を決め、手順4の残りブロックを実回路化する。** 外形、キー間隔、スイッチ／スライダー位置などの外観は維持する。OLEDはRev.Aと同じWaveshare 0.96inch OLED (C)に決定済み。

### 検証と発注の責務

「実測してからschematicを決める」のではなく、確認対象を限定した検証用schematicを先に作る。今回の順序は次の通りとする。

1. AIが `emiuet-validation/hardware/val-core-01/VAL-CORE-01.kicad_sch` を現行方針（single USB-C、Rd＋comparator、候補3.3 V、入力保護、5V LED branch）へ更新し、接続、部品候補、テストポイント、未確定値を記録する。
2. AIがnetlist/ERC、BOM、部品datasheet、V0–V2の測定手順を揃える。ここでのschematicはVAL-CORE-01の検証範囲に限定し、製品Rev.Bの78キーPCBを確定したことを意味しない。
3. オーナーが回路の意図、部品候補、費用・調達条件、測定可能性を監修し、発注可否を判断する。AIは発注や製造承認を代行しない。
4. 発注・組立後は、オーナーが実機を測定する。AIは測定ログの整理、判定、回路・FW候補の修正案を担当する。実測結果が出るまで、製品の採用品・電力適合・製造可否は未確定とする。

発注判断に必要な資料が揃った時点で、AIは作業を止め、オーナーへの確認を一項目ずつ行う。各回答を回路図・BOM・測定手順へ反映してから、次の確認へ進む。

VAL-CORE-01の現行READMEとvalidation matrixは `emiuet-validation` 側の正本であり、同リポジトリの回路図が旧TUSB320前提のままでは発注対象にしない。

- オーナー判断で、TUSB320をRd＋TLV7022 comparatorへ置換した。TUSB320はType-CのtSinkAdj（60 ms）を満たせないため。decisions §9、history、pinout、firmwareに反映済み。
- schematicは101→111部品。CC検出、RGB_DATA pulldown、OLED connector（Rev.A footprintを流用）を追加し、U2・R3を撤去した。ERCは**35 errors / 167 warnings**（初期50 / 174）。新ブロックはnetlistと描画で確認済み。回路はまだ完成していない。
- firmware: `tusb320.c` を `usb_cc_detect.c` へ置換し、descriptorを500 mA宣言にした。一時host simulationはPASS（Rp低下の反映は17 ms）。ESP-IDF 5.3.4のRev.B構成buildは成功し、`firmware/main` のwarningは0件（2026-10-05）。実機は未実施。
- 独立レビューを2回実施した（TUSB320版／置換後）。指摘は1件を除き対応済み（回路ノート末尾）。

### 確認状況と未解決の判断事項

- **MIDI送信task（2026-10-05 対応済み）:** USB/TRSの送信taskは100 Hz設定でidle待ちが0 tickになっていた。BLEには10 msのqueue待ちがあった。3系統をtask notificationで起こす方式へ変更した。
  - producerはqueueへの積み込みかcoalesce値の更新を先に済ませてから通知する。送信taskは全部を出し切ってから待つ。この順序なので、通知を取りこぼさない。
  - USBで送信が拒否された場合（FIFO満杯・未mount）は、そのデータを保持し、必ず1 tick blockしてから再送する。通知でこの待ちを短絡させず、低優先度のTinyUSBへ実行機会を渡す。再送時は新しいPB/CC1値を古い値で上書きせず、16件ごとの挿入カウンタも維持する。
  - 切断時は従来どおり保留分を破棄する。再接続はATTACHED eventとstate taskの両方から送信taskを起こす。
  - eventの順序と、PB/CC1の集約・挿入位置（16件ごとと空になった時、TRSは8件ごと）は従来どおり。
  - host simulationで、順序、FIFO満杯時の再送、取りこぼし窓、切断・再接続、queue満杯を確認した。実機は未確認。
- **FreeRTOS tick（2026-10-05 1000 Hzへ変更済み）:** 100 Hzでは10 ms未満の待ちが0か10 msに丸められていた。そのため、matrix scanは設計の5 msではなく10 ms周期で動き、押鍵の確定は約20–30 ms（設計約10–15 ms）だった（推論）。
  - `sdkconfig.defaults`/`sdkconfig.ci` を1000 Hzにした。手元の生成済みsdkconfigも同じ行を更新した。
  - 1000 Hz未満では `matrix_scan.c` がbuildを止める。
  - 時間指定はすべて `pdMS_TO_TICKS` 経由で、ms単位の設計値は変わらない。tick割込みの負荷増と実際の押鍵遅延は実機で確認する。
- 実機でのCC応答時間、PD sourceのCC波形、Default時の総電流、MIDI送信と押鍵の実機遅延、task WDTの有無は未実施。
- ローカルの `firmware/build-revb/sdkconfig` は古い値（TRS無効、100 Hz）のままdefaultsと食い違っていたので、defaultsから再生成した。別PCでも同じ現象が起き得る。tickが古い場合は `matrix_scan.c` がbuildを止める。
- **手順3の候補比較（2026-10-05）:** 3.3 VはTPS62162 buckを第一候補、AP2112K-3.3を熱評価付き代替候補とした。VBUS保護はTVS＋過電流保護、5V_LED branchはTPS2553級のcurrent-limited switchを候補とし、USB D+/D−は低容量ESD array、CCは低漏れ保護を別条件で選ぶ。MPN・footprint・突入・実測電流は未確定。

今回のレビュー確認（2026-10-05）:

- USB再送時の新しいPB/CC1値の上書き、通知連発による再送待ちの短絡、FIFO満杯時の挿入カウンタのリセットを修正した。
- 既存の一時host harnessを修正後の実ソースに対して再実行し、順序・coalesce・FIFO満杯・通知取りこぼし窓・切断／再接続・queue満杯、および今回の再送競合と16件ごとの挿入を確認した。CC検出・configured/suspend別budgetの一時host検証もPASS。永続的なtest suiteは追加していない。
- ESP-IDF 5.3.4のRev.B buildはPASS（1000 Hz、TRS/RGB有効）。実機でのscheduler・USB転送・演奏遅延の保証ではない。
- OLED/RGB biasブロックを表題欄と重ならない位置へ移した。移動前後のnetlist接続は一致し、再描画を確認した。ERCは引き続き35 errors / 167 warnings、未割当footprintは10部品。製造不可。

確認出力: `build/hardware/20261005T072214.395967Z/`。出力はgit対象外であり、別環境では下記commandで再生成する。hash記録は依存の検出用で、別PCのlibrary同一性を自動保証しない。

## 次のAIが行うこと

1. `AGENTS.md` が示すgovernance、README、decisionsを読み、`git status --short`を確認する。未commitの成果も現在地の一部。既存変更を消さない。着手前からある `.vscode/settings.json` は今回の対象外。
2. 「確認状況」に未解決の判断事項があれば、オーナーの回答を先に反映する。監査のやり直しやRev.A全面保存には戻らない。
3. 3.3 V regulatorを選ぶ。ESP32-S3の電源要求、OLED/comparator負荷、発熱、CC VREF精度（回路ノートの誤差予算）を条件にする。あわせてVBUS入力保護（TVS、fuse/eFuse）、突入電流、CC/D±のESD、LED電源の遮断手段を具体化する。Default 500 mAの内訳は未測定項目を明示し、LED budgetだけでUSB適合を宣言しない。
4. 続いてMIDI IN/OUT、78キーmatrix、slider/button、pixel bypassを小ブロックごとにnative schematicへ追加する。型番・pin・footprintは一次資料で照合する。
5. 各ブロックでnetlist/ERC→描画→独立確認。既存PCBへ一括updateしない。機構照合では表裏・原点を揃え、0.05 mm等の差を無断で均さない。外観と衝突する新MIDI IN等は具体案を作って確認する。
6. 終了前にこの文書の状態・結果・次の一手を更新する。chat履歴、特定AIのmemory、tool session IDに依存しない。採用変更は対応する正本へ反映する。

再開依頼はこれだけでよい:

> このリポジトリのAGENTS.mdに従い、docs/rev-b-roadmap.mdの「次のAIが行うこと」から作業を続けてください。未commitの成果も引き継いでください。

同じフォルダならCodexでもClaude Codeでも使える。別PCへ移る場合は、未commitの変更を含む作業ツリーとgovernanceを渡す必要がある。リモートへpush済みとは限らない。

## 確認コマンド

リポジトリrootのPowerShellから:

```powershell
& 'C:\Program Files\KiCad\10.0\bin\python.exe' tools\verify_hardware.py
```

他の環境ではPython 3.10以上とKiCad 10.0.3を用意し、`python tools/verify_hardware.py --kicad-cli <実行ファイル>`。成果は新しい `build/hardware/<UTC>/` に出る。終了コード0は機械確認合格、1は設計違反、2は環境／tool失敗。現状の1をtool故障と誤認しない。`summary.json`、`erc.json`、`netlist.xml`、`bom.csv`、`svg/`を確認する。DRC/parity/実機は未検証として残る。

firmwareは、このPCのESP-IDF 5.3.4（`C:\Users\emnye\esp\v5.3.4`）でbuildできる。システムのPythonではexport.ps1が失敗するので、IDF同梱のPython 3.11を先にPATHへ入れる。PowerShellでリポジトリrootから:

```powershell
$env:PATH="$env:USERPROFILE\.espressif\tools\idf-python\3.11.2;$env:USERPROFILE\.espressif\tools\idf-git\2.44.0\cmd;$env:PATH"
$env:IDF_PYTHON_ENV_PATH="$env:USERPROFILE\.espressif\python_env\idf5.3_py3.11_env"
. C:\Users\emnye\esp\v5.3.4\esp-idf\export.ps1
cd firmware; idf.py -B build-revb -D SDKCONFIG=build-revb/sdkconfig -D "SDKCONFIG_DEFAULTS=sdkconfig.defaults;sdkconfig.rev-b.defaults" build
```

既存の `build-revb/sdkconfig` はdefaultsで上書きされない。defaultsを変えたら、その行を合わせるか、ファイルを退避して再生成する。

## アムニェカさんの次の作業

1. まずこの表の現在地を確認してください。外観維持、OLED（Waveshare (C)）、CC検出方式（Rd＋comparator）の回答は反映済みで、再回答は不要です。
2. 任意のAIで上の再開依頼を実行してください。次はAI側の3.3 V・保護回路の設計で、部品発注はまだ先です。firmwareのbuild確認はAIが行えます。
3. 回路と具体部品案が揃ったら、外観と新コネクタの両立案を確認してください。その後、既存 `emiuet-validation` のVAL-CORE-01手順で試作・測定へ進みます。現在のRev.B firmwareをRev.Aへそのままflashする段階ではありません。

物理測定では、Default/1.5 A/3 A、attach/detach/suspend、白色最大負荷、3.3 V温度・ripple、RGB波形を確認し、V0–V2後に製品PCBでV3へ進む。新しい並列試験体系は作らない。

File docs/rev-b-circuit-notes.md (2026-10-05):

# Rev.B 回路設計ノート

更新: 2026-10-05。内部レビュー用。製品判断は [decisions.md](decisions.md)、進捗は [ロードマップ](rev-b-roadmap.md)。ここでは設計根拠、観測と未検証の境界を記録する。製造承認ではない。

## 外観を維持するための機構参照

オーナー指定は外形・キー間隔・スイッチ／スライダー位置を含む外観維持。OLEDはRev.Aと同じWaveshare 0.96inch OLED (C)（decisions §12）。

KiCad 10.0.3のpcbnewで既存ファイルを読み取り、以下を抽出した。座標は各ファイル内のfootprint原点であり、筐体寸法や部品中心を実測した値ではない。Edge.Cuts bounding boxは線幅も含むため、その値で新しい長方形を描き直さない。曲線・切欠き・穴は元の形状を参照する。

| 参照 | 抽出した値（mm） | 注意 |
|---|---|---|
| `hardware/kicad/Emiuet.kicad_pcb` | Edge.Cuts bbox 297.05 × 102.45 | Rev.Aの機構参照。電気回路はRev.Bと非互換 |
| 同PCBの78キー | 主な列間隔18、行間隔17 | col0→1は18.05。差0.05を無断で補正しない |
| 同PCBのSW1_0 / SW1_12 / SW6_0 | (313.85,51.2) / (97.8,51.2) / (313.85,136.2) | Choc hotswapの既存原点 |
| 同PCBのRV1 / RV2 / RV3 | (81.25,100.06) / (69.24,100.06) / (57.25,100.05)、各90° | 10k、既存35mm slider footprint。型番の購買照合は未完 |
| `Emiuet_plate/Emiuet_plate.kicad_pcb` | bbox 297.05 × 102.45、キーcutout pitch 18 × 17 | PCBと座標系・左右が異なる。組立照合前に座標を転記しない |
| `Emiuet_topLeft/Emiuet_topLeft.kicad_pcb` | bbox 24.05 × 102.449966 | 穴と形状を維持 |
| `Emiuet_topRight/Emiuet_topRight.kicad_pcb` | bbox 38.589997 × 102.489976 | slider cutout等を維持 |
| 同PCBのOLED Brd2 | (69.25,63.6)、B面、180°。外形26.1 × 26.1、7pin 2.54 mm、取付穴φ2.5 ×4（22.4 × 21.9間隔） | Waveshare (C) 26 × 26 mmと一致。plate/topRight cutoutも同形状 |

参照PCB SHA-256: `642400cf5f23b2d769d949b8072a8d1e20ea1ca32fac013d5ae9d9dc68474a3b`。
plate: `a884d3efe96c41c683d391f9426ecab2c7bc2a514b024a8397c090ecf8b00b1b`。
topLeft: `fe5e530ed70193449db73d8b35824400695cdb161e0ee251ac769437b036b4e0`。
topRight: `08d0631b87b2ed6dc95a61d2c5c71e473350d10ceeefdf5252005be4c78a843a`。

PCBとplateは同じviewではないため、sliderが左右反対に見えることだけで誤りと断定しない。表裏・組立原点を合わせた重ね合わせは未実施。旧電池／role用スイッチの位置維持と電気的用途、新MIDI IN開口は別問題であり、未定義機能を割り当てない。

## 実回路化したブロックと根拠

| ブロック | schematic上の構成 | 未完の条件 |
|---|---|---|
| ESP32-S3 reset/BOOT | R1 10k + C2 1uのEN RC、SW1 RESET、R2 10kとSW2 BOOT、C3 10u/C4 100n | GPIO46 strap、実電源立上り、switch footprint、電源設計を照合 |
| USB-C CC検出 | R8/R9 5.1k 1% Rd、R10/R11 100k + C7/C8 10n、R12 38.3k/R13 10k/C9 100nのVREF、U6 TLV7022DGKR、R6 10k pull-up、C5 100n bypass | CC ESD、Rd/VREFのMPN、実機の応答時間 |
| I2C / OLED | R4/R5 4.7k、J4 Waveshare 0.96inch OLED (C)（Rev.A footprintを流用） | module側pull-upとの合成値、RES/DC/CS開放の実機確認 |
| RGB buffer | U4電源/OE/GND接続、C6 100n、R7 68Ω直列、R14 100k RGB_DATA_3V3 pulldown | 68Ωは候補。各pixel bypass、bulk、信号波形は未検証 |

根拠はメーカー一次資料: [Espressif schematic checklist](https://docs.espressif.com/projects/esp-hardware-design-guidelines/en/latest/esp32s3/schematic-checklist.html)、[TLV7022 Rev.F](https://www.ti.com/lit/ds/symlink/tlv7022.pdf) §5、6.1、6.10、[SN74AHCT1G125 Rev.P](https://www.ti.com/lit/ds/symlink/sn74ahct1g125.pdf) §8.3（入力をfloatさせない）、[Waveshare 0.96inch OLED wiki](https://www.waveshare.com/wiki/0.96inch_OLED_Module)。ENの10k/1uは推奨初期値で、全電源条件を保証する値ではない。

追加passiveは0603 footprintを仮指定したが、MPN・定格・DC bias・供給性は未確定。SW1/SW2は回路上の参照番号で、Rev.A PCBの同番号とは同一部品を意味しない。U6はKiCad標準のLM2903 symbol（LM393と同じpin配置: OUTA 1、INA− 2、INA+ 3、VEE 4、INB+ 5、INB− 6、OUTB 7、VCC 8）で描き、TLV7022 Pin Functionsと照合した。

## USB-C電流検出の設計

TUSB320を撤去した理由はdecisions §9とhistoryに記録した。ここでは置換回路の根拠を残す。

- **閾値:** Type-C sinkのvRd範囲はDefault 0.25–0.61 V、1.5 A 0.70–1.16 V、3 A 1.31–2.04 V。規格上の判定閾値0.66 Vに対し、VREFを0.683 V（3.3 V × 10k/48.3k）とした。3.3 V ±1.5%、抵抗1%、offset ±8 mV、hysteresis最大15 mVを重ねた判定点は約0.645–0.72 V。Defaultを1.5 Aと誤認する側（0.61 V以下で判定）には約35 mVの余裕がある。代償として、0.70–0.72 V付近の正規1.5 A sourceをDefault扱いにし得る（明るさが下がるだけ）。offset/hysteresisの規定条件はVCM = VS/2で、動作点0.68 V付近の値は未確認。3.3 V regulatorの精度が決まったら再計算する。
- **極性:** IN+ = VREF、IN− = CCx。どちらかのCCが閾値を超えるとopen-drain出力がLowになり、2出力のwired-ORで `USB_CC_1A5_N` を作る。comparator未給電（POR中Hi-Z、§7.4）と出力開放はpull-upでHigh（Default）に倒れる。出力段のLow固着、GPIO37のGND short、CCx_FILTがVREFより高い電位へshortした場合は1.5 A側になる。
- **未給電時:** TLV7022の入力はVCCと無関係に5.5 Vまでfault tolerant（§7.4.1）、絶対最大はVEE基準で7 V（§6.2）。Sourceは3.3 Vが立ち上がる前からCCにRp（最大約2.04 V）を出すが、VCCへの逆流経路はない。R10/R11 100kでさらに電流を制限する。
- **PD通信の除去:** PD SourceはSink応答がなくてもCC上でBMC通信を送る。100k/10n（τ 1 ms）で平滑化し、firmwareで上昇方向を100 ms安定まで待つ。Rd側から見た追加容量はR10/R11で切り離される。
- **応答時間:** Type-Cはsinkに、Rp変化から60 ms以内（tSinkAdj）の電流低下を求め、変化判定に10–20 ms（tRpValueChange）を許す。firmwareは10 ms周期で読み、低下を2 sampleで反映する（最大約20 ms）。renderer周期16 ms（tick 1000 Hz）とRMT送出（約2.4 ms）を足した最悪見積もりは約38 ms。host simulationでは低下反映17 ms。実機の測定は未実施。
- **scheduling:** `usb_cc` taskは `configMAX_PRIORITIES - 1` とし、他taskの挙動に左右されないようにした（処理は10 msごとに数µs）。core 0のMIDI送信taskがidle時に回り続ける問題は、通知方式への変更で解消した（ロードマップ「確認状況」）。rendererはcore 1の優先度4で、core 1に常時回るtaskはないと読んでいる。実機でtask WDTと応答時間を確認する。
- **PD通信中の誤ったDefault判定:** 1.5 A/3 A sourceがBMCを送っている数msの間は、filter後の電圧が判定点を下回り得る。2 sample連続が必要なため、10 msを超えるburstでなければDefaultへ落ちない。この誤判定は安全側。PD sourceでのCC波形は実機で確認する。
- **残る保護:** CC線のESDは、USB D+/D−と同じinput protection blockで扱う（未選定）。

## USBとLED電力の状態

| 状態 | firmwareのRGB budget |
|---|---|
| 起動直後（CC判定前） | 0 |
| Default、USB未configuredまたはsuspend | 0 |
| Default、configured、非suspend | 200 mA（Kconfig既定） |
| Rp ≥ 1.5 A（3 Aを含む） | 1000 mA（Kconfig既定）。3 Aへ増やさない |

budget 0はrender出力を黒にするだけで、LED素子の待機電流やMCU/OLEDの電流は残る。USB configuration descriptorのbMaxPowerは250 mAから500 mAへ変更した。Defaultで動く全体の電流（MCU、OLED、78 pixelの待機電流、LED 200 mA）は250 mAを超える見込みであり、宣言と実消費を一致させるため。

Default 500 mAの内訳は、MCUのUSB/BLE動作電流とSK6812 MINI-Eの待機電流が未測定のため、まだ閉じていない。OLEDは全点灯で約25 mA（Waveshare wiki、3.3 V）。V0–V2でこれらを測り、200 mA設定を確定または下げる。1.5 A/3 A時のsuspend電流の扱いは、[USB-IF functional tests](https://www.usb.org/sites/default/files/USB%20Type%20C%20Functional%20Test%20Specification%202024%2003%2003.pdf) のTD4.10系列とValidation時に照合する。

## 3.3 V電源の選定で残っていること

| 案 | 設計上の特徴 | 現時点の扱い |
|---|---|---|
| AP2112K-3.3系LDO | 5→3.3 Vで0.3 Aなら約0.51 W、0.5 Aなら約0.85 Wを発熱 | schematicのplaceholder。定格だけで採用しない |
| TPS62162等のbuck | 3.3 V固定・1 A級の候補。inductor/capacitorとlayoutが必要 | 候補比較まで。採用・在庫確認は未完 |

根拠: [AP2112 datasheet](https://www.diodes.com/datasheet/download/AP2112.pdf)、[TPS62162 datasheet](https://www.ti.com/lit/ds/symlink/tps62162.pdf)。発熱値は単純な(Vin−Vout)×Iの計算で、温度予測ではない。ESP32-S3の電源能力要求、OLED等の負荷、USB総電力、温度条件を揃えて選定する。input protection、inrush、LED電源の遮断手段も同じ電力設計で決める。

### 手順3の暫定選定

現時点では **TPS62162を3.3 V buckの第一候補**とする。TIの製品資料では、入力3–17 V、固定3.3 V、1 A、同期整流、軽負荷効率、enable、power-goodを備える。USB VBUSの5 Vから3.3 Vを作るため入力範囲に余裕があり、ESP32-S3の無線・USB peakを含む可能性のある300 mA以上の負荷で、AP2112系LDOより発熱を抑えやすい。これは候補比較上の判断であり、実測負荷・温度・layoutを確認するまで採用品とはしない。

AP2112K-3.3は回路が単純で候補から外さないが、5 Vから3.3 Vへの損失が負荷に比例するため、300 mAで約0.51 W、500 mAで約0.85 Wとなる。OLED/comparatorだけでなくESP32-S3のpeakを含む実測で、この熱を許容できる根拠が得られた場合に限り採用を再検討する。

入力保護は次の分離を第一候補とする。

- USB D+/D−: TPD2EUSB30A等の低容量ESD arrayをコネクタ近傍に置く。TI資料上、TPD2EUSB30AはUSB 3.0向け低容量保護品だが、EmiuetはUSB 2.0であり、実際のclamp・layout・ESD帰路を確認してから型番を固定する。
- VBUS: TVS、過電流保護、bulk容量をコネクタ近傍に配置する。TPS2553は2.5–6.5 V入力、0.075–1.7 A adjustable current limit、reverse blockingの電源switch候補であり、5V_LED branchの突入・短絡制限候補とする。MCU/3.3 V branchを同じswitchで遮断するかは、USB enumerationとfault時の要求を整理してから決める。
- CC1/CC2: comparator入力のRCとRdは既存設計を維持し、CC線のESD保護はD+/D−用とは別に低容量・低漏れ条件で選ぶ。CCのclampが判定電圧を変えないことを確認する。

Default 500 mAの内訳は、ESP32-S3（USB/BLE peak）、OLED、comparator、SK6812のidle電流、regulator損失を分けて測定する。LED rendererの200 mA budgetはこの総量の保証値ではなく、測定前にUSB適合を宣言しない。

## 確認結果と限界

111 components。KiCad 10.0.3でERCは35 errors / 167 warnings（初期50 / 174）。残りはregulator・MIDI未接続などに由来し、今回のブロックからは新しい違反は出ていない。CC検出、OLED、R14の各pinの接続はXML netlistで確認し、描画も目視で確認した。ERCをignoreで消してはいない。未接続電源・MIDI等が残るので製造不可。

`usb_power.c` と `usb_cc_detect.c` の実ソースを、一時的なFreeRTOS/GPIO stubとMSVC `/W4 /WX` でcompileした。そのうえでCC pinを模擬し、次のassertがPASSした。

- 起動直後
- 上昇方向のdebounce
- 低下時の応答時間
- 1 sampleだけのglitchの除去
- configured/suspend別のbudget

これは単体ロジックの確認。ESP-IDF 5.3.4のRev.B構成buildは成功した。TinyUSBとの実動作と実機はUNVERIFIED。

独立レビュー1回目（2026-10-05）は、TUSB320版の差分を対象に行った。指摘の扱いは次のとおり。

- TUSB320LAIの型番とアドレスの不一致、Rp追従の遅れ、周期消灯、INT_N未clear: TUSB320の撤去で解消。
- RGB_DATA_3V3のfloat: R14を追加して対応。
- descriptorの過少宣言: 500 mAへ変更。
- DETACHEDとstate taskの競合: 書き込みをstate taskだけにして解消。
- verify toolのlibrary path優先: CLIと同じinstallを常に使うよう修正。
- 未対応で残るもの: 電源rail未接続、footprint未割当、EN_RESET等の残りERC。

独立レビュー2回目（同日）は、置換後のCC検出・OLED・firmware・文書を対象に行った。netlist、TLV7022のpin配置と極性、VREF、OLED footprintの配置復元（11 padとbboxが一致）は問題なしとされた。指摘の扱いは次のとおり。

- core 0の飢餓（blocker）: `hid_keyboard_tx` は0 tick待ちのため、USB未mount中に回り続けていた。1 tick待ちに修正した。`usb_cc` は最高優先度へ上げた。MIDI送信taskのidle `taskYIELD()` loopは、オーナー承認後に通知方式へ変更した。
- 判定点上限0.72 V、5.5 V fault toleranceの表記、故障モードの区別、PD中の誤ったDefault判定: 上の設計節に反映した。
- auditとREADMEの食い違い、footprintに残ったboard由来の値、`stable` のwrap、stackの余裕: 修正した。

tSinkAdjとtRpValueChangeは二次情報（Zephyrの仕様表引用）で照合した。vRdの範囲と0.66 V閾値は一次資料で未照合。USB Type-C仕様本文での照合は、3.3 V regulator決定時のVREF再計算と同時に行う。

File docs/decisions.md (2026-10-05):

# Emiuet 現行設計判断

この文書はEmiuetの現在有効なproduct decisionsの正本です。実装済み範囲や作業履歴ではなく、変更時に守るべき目的、主従関係、非自明な制約を記録します。撤回済みのRev.A/旧Rev.B判断は `history/rev-a-and-superseded-decisions.md` に分離します。

## 1. Product identity: guitar-first instrument

Emiuetはguitarists向けのfretboard MIDI instrumentです。general-purpose MIDI controller、piano-style keyboard、商用MIDI keyboardとのfeature parityを目的にしません。

strings、fret positions、chord shapes、voicings、guitar由来のmuscle memoryを中心に設計します。USB、RGB、TYPE modeなどのsubsystemはこの演奏体験を補助する手段であり、product identityより上位ではありません。

## 2. 6 × 13 playing surface

key matrixは6 rows × 13 columnsに固定します。13 positionsは数値上の対称性ではなく、E-root/A-rootを含むguitar由来のvoicingをoctave shiftや強制的な省略なしで扱うために選択しています。

PCB幅とrouting complexityが増えても、guitaristsのharmonic thinkingを維持することを優先します。

## 3. Pitch Bend

Pitch Bendはstring bendingに対応する上方向のみ、linear curve、固定maximum range、自動center returnとします。下方向または対称的なbendへ一般化しません。

これは実装上の暫定制限ではなく、予測可能な演奏表現を守る意図的な制約です。

## 4. Constrained MPE

任意のStringwise Bend modeでは、各stringを独立MIDI channelへ割り当てます。Pitch Bendは直近に演奏したstringを対象とし、bend中は対象を固定します。full generalized MPEではなく、guitar-like mental modelを保つ限定的なchannel separationを採用します。

表現力を増やす場合も、channel managementの複雑さが演奏の予測可能性を損なわないことを判断基準にします。

## 5. Minimal OLED

OLEDはperformance feedbackに限定します。menu-driven parameter editorや高密度情報表示を本体UIの中心にしません。複雑な設定UIが必要な場合は外部device側を優先し、演奏中の視覚的負担とfirmware責務を増やしません。

## 6. MIDI transport philosophy

USB、TRS、BLEは独立したtransportです。musical logicはtransport I/Oを待たず、dedicated sender taskへ0-waitでenqueueします。通常のrealtime priorityはTRS > USB = BLEで、同時出力を許可し、自動fallbackは前提にしません。

Pitch BendとCC#1のようなcontinuous controlはchannel単位でcoalesceでき、Note On/Offなどのdiscrete eventは順序を維持します。BLE transportがstubの間はroutingで有効化しません。

TRS MIDIは薄型筐体に適したType-Aを使用し、5-pin DIN MIDIは採用しません。Rev.BではType-A TRS MIDI OUTを維持し、isolated Type-A TRS MIDI INも追加します。

## 7. Auxiliary TYPE mode

USB HID Keyboard Mode (`TYPE`) はdesk上での短いtext entry、search、navigation、shortcutを補助する機能です。EmiuetをPC keyboardとして再定義せず、通常keyboardの速度やergonomicsを目標にしません。

MIDIとHID Keyboardは一つのpersistent composite USB Deviceとして列挙し、mode switchingでUSBを再enumerateしません。4 corner keysを2秒保持してmodeを切り替え、transition時はtracked note/keyとpending stateを解放します。actual layoutは `keyboard-mode.md` をユーザー向け正本とします。

## 8. Rev.B USB and power

Rev.Bはsingle USB-C、USB Device/UFP onlyです。一つのportで5 V power、USB MIDI、USB HID、firmware flashingを担います。USB Host、DRP、OTG role switching、Host VBUS source、runtime role switching、internal battery、charger、PowerPathは採用しません。

power architectureは次の通りです。

```text
USB-C VBUS
→ protection / input conditioning
→ 5 V rail → RGB LEDs
             └→ 3.3 V regulator → ESP32-S3 / OLED / logic
```

hardware ceilingは約5 V / 1.5 Aです。mobile useはexternal USB power bankを使用します。

## 9. USB-C current detection

CC1/CC2にはそれぞれ5.1 kΩ Rdを置き、各CC電圧をdual comparatorで常時監視します。comparatorはType-Cの1.5 A閾値（vRd 0.66 V）を安全側へ寄せたreferenceと比較し、Rp ≥ 1.5 Aかどうかを1本のGPIOで報告します。USB Host、DRP、role control、VBUS source control、orientation検出は持ちません（USB 2.0 onlyのためorientationは不要）。

Source currentは接続中にも下がり得るため、sinkはRp変化から60 ms以内（Type-C tSinkAdj）に消費電流を下げる必要があります。TUSB320はattach時以外の電流検出更新にI2C soft resetと再debounceを要し、この条件を満たせないため、2026-10-05のオーナー判断で採用をやめました。detectorの未給電・出力開放はDefault側に倒れる構成とします。出力Low固着など、全故障をDefaultとして検出できる構成ではありません。

Default advertisementではUSB 2.0 500 mAとUSB 3.x 900 mAをCCだけから区別できないため、firmwareは安全側のLED budgetを選び、USB configuredかつ非suspendの間だけ許可します。1.5 A/3 Aは同じ1.5 A hardware ceilingへ丸めます。

## 10. RGB fretboard visualization

SK6812 MINI-Eを全78 keysへ搭載し、dataはsingle serpentine daisy chain、5 V/GNDはparallel distributionとします。physical chain orderと6 × 13 logical fret/string coordinatesをfirmware mappingで分離します。

ESP32-S3 GPIO38から5 V AHCT bufferとseries resistorを介してDINへ接続します。各pixelのlocal bypassと5 V bulk capacitanceを設けますが、部品値はValidation前の確定仕様としません。

rendererはEspressif `led_strip`、RMT backend、ESP32-S3 DMAを使用し、bit-bangを採用しません。USB/TRS MIDI RX → parser → LED state → rendererを分離します。

Note On/Offによるfretboard visualizationは初期機能として採用します。global brightnessなどのdevice settingを標準musical CCへ割り当てません。外部LED control protocolは未確定で、将来SysEx等の明示的なprotocolとして検討します。

## 11. Rev.Bから撤回した回路

- charging-only second USB-C
- Li-ion cell/connector、NTC、BQ24074、charge configuration
- battery protection dependency、PowerPath、BAT_VSENSE、charge/PG GPIO
- TPS61023 battery-to-5 V boost
- LM66100 Host VBUS source path
- Host/DRP/role-switch circuitry

TPS61023とLM66100にはRev.Bで別用途がないため採用しません。Rev.A manufacturing dataはhistoryとして保持し、Rev.B PCBはcurrent schematicから別工程で再設計します。

## 12. Rev.Bで維持する外観・機構

2026-10-05のオーナー指示により、Rev.Aの外形寸法、キー間隔、スイッチとスライダーの位置を含む外観・デザインを維持します。回路変更を理由に操作面を再配置しません。

OLEDはWaveshare 0.96inch OLED Module (C)（SSD1315、128 × 64、上部16 px黄／下部青、26 × 26 mm、7-pin）を採用し、I2C（0x3C）で接続します。Rev.Aの取付穴・plate/top cutout、firmwareの描画（u8g2 SSD1315、黄帯16 px）がこのmoduleを前提としており、開発資産と外観をそのまま活かすためです（2026-10-05オーナー指示）。

既存PCBとplate/topの形状・穴・操作部位置を機構の参照とします。基板間の座標系・表裏の対応は組立として照合し、差異を勝手に均して修正しません。USBポート削減とMIDI IN追加に伴う開口の扱いなど、外観維持と衝突する変更は具体案を作ってオーナーに確認します。抽出結果と未確認事項は `rev-b-circuit-notes.md` に記録します。

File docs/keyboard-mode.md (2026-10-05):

# USB HID Keyboard Mode

## Positioning

USB HID Keyboard Mode (`TYPE`) is an auxiliary input feature for short text
entry, search, file operations, navigation, shortcuts, and occasional coding
input. Emiuet remains first and foremost a fretboard MIDI instrument. Its
6 × 13 ortholinear playing surface is not intended to reproduce the speed or
ergonomics of a conventional PC keyboard.

## Modes and switching

- `MIDI`: matrix presses generate MIDI notes; no HID keyboard reports are generated.
- `TYPE`: matrix presses generate USB HID keyboard reports; matrix presses and sliders do not generate MIDI.

Hold all four physical corner keys—row 1 columns 1 and 13, and row 6 columns 1
and 13—for two seconds to switch modes. The widely separated, long-hold chord
reduces accidental switching during performance. A mode change does not restart
or re-enumerate USB.

Every transition releases tracked MIDI notes or the complete HID report and
returns Pitch Bend to center. Because Rev.B is powered by its single USB-C port,
physical detach also powers the unit down rather than leaving a self-powered USB
session active.

## Base layer

Rows are shown left to right as physical columns 1–13. `MODE` marks a corner
reserved for the switching chord.

| Row | 1 | 2 | 3 | 4 | 5 | 6 | 7 | 8 | 9 | 10 | 11 | 12 | 13 |
|---|---|---|---|---|---|---|---|---|---|---|---|---|---|
| 1 | MODE | 1 | 2 | 3 | 4 | 5 | 6 | 7 | 8 | 9 | 0 | - | MODE |
| 2 | Tab | Q | W | E | R | T | Y | U | I | O | P | [ | ] |
| 3 | Caps | A | S | D | F | G | H | J | K | L | ; | ' | Enter |
| 4 | LShift | Z | X | C | V | B | N | M | , | . | / | RShift | Backslash |
| 5 | LCtrl | LGUI | LAlt | Fn | Space | Space | Space | Space | Space | RAlt | Left | Down | Right |
| 6 | MODE | Esc | Grave | = | Backspace | Delete | Insert | Menu | Home | End | PageUp | Up | MODE |

The usages follow US keyboard positions. The active host keyboard layout
determines the character produced, so symbol legends may differ on other layouts.

## Fn layer

Fn is momentary and changes the active mapping only while held.

| Row | 1 | 2 | 3 | 4 | 5 | 6 | 7 | 8 | 9 | 10 | 11 | 12 | 13 |
|---|---|---|---|---|---|---|---|---|---|---|---|---|---|
| 1 | MODE | F1 | F2 | F3 | F4 | F5 | F6 | F7 | F8 | F9 | F10 | F11 | MODE |
| 2 | Tab | Home | Up | End | — | — | — | — | — | — | PrintScreen | ScrollLock | Pause |
| 3 | Caps | Left | Down | Right | — | — | — | — | — | — | — | — | Enter |
| 4 | LShift | — | — | — | — | — | — | — | — | — | — | RShift | — |
| 5 | LCtrl | LGUI | LAlt | Fn | Space | Space | Space | Space | Space | RAlt | Home | PageDown | End |
| 6 | MODE | F12 | Esc | = | Backspace | Delete | Insert | Menu | Home | End | PageUp | Up | MODE |

The USB boot-keyboard report supports six simultaneous non-modifier usages plus
all modifier bits. This covers shortcuts such as Shift+letter, Ctrl+C, Ctrl+V,
and Ctrl+Z. The diode-equipped matrix continues to scan every physical key; only
the HID boot-keyboard report is limited to 6KRO.

## OLED feedback

The top status area shows `MIDI OCT:n` in MIDI mode. TYPE mode shows `TYPE L0
C:OFF`, or the current layer and host-reported Caps Lock LED state.

## USB boundary

Rev.B exposes one persistent full-speed USB composite Device with MIDI and HID
Keyboard interfaces. MIDI/TYPE switching changes only the internal event route.
USB Host, DRP/OTG role switching, Host VBUS sourcing, and runtime role changes
are outside the product scope.

The single USB-C port also powers the instrument and supports native USB firmware
flashing. Emiuet observes only the USB-C Source current advertisement, to limit
LED power; it does not control USB roles.

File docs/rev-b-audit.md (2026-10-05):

# Rev.B 設計・開発環境監査

監査日: 2026-10-05。対象: `feat/revb-usb-powered-rgb`、`1fff3fd141df0f5aa6b7872cf6fc79add14f0f3e`。
開発者・AI向けの現状評価と移行提案であり、製品仕様の第二の正本ではない。有効な判断は [decisions.md](decisions.md)、GPIO割当は [pinout-v3.md](pinout-v3.md) を参照する。以下の状態は監査時点の記録である。特に、TUSB320をCC detectorとして残す前提（§1–3）は、その後decisions §9でRd＋comparatorへ置換された。

## 1. 結論と現在地

**Rev.Bはアーキテクチャと一部firmwareが先行し、製造可能な回路設計はこれからの段階。** 回路図は存在するが、電源・MIDI・入力系の実回路が未完成であり、「部品値調整とERC cleanupだけで完成する」状態ではない。既存PCB/BOMをRev.Bとして使うことはできない。

- 残す: guitar-firstの6×13配列、演奏表現、single USB-C Device/UFP、native USB、外部USB給電、5V RGB＋3.3V logicという設計意図。firmwareのtransport分離とGPIO割当も照合の出発点になる。
- 作り直す: 電源・保護・reset/BOOT・MIDI・matrix/UIを含む完全なschematic、部品選定、PCB、BOMと製造出力。既存draftを修復するか新規に起こすかは、小さい差分に固執せず読める成果で決める。
- 持ち越さない: 内蔵電池、charger、PowerPath、boost、dual USB、Host VBUS、旧PCBの接続。Rev.Aの完全な別系統保存や履歴の追加整理には時間を割かない。
- EDAは**KiCad継続を第一推奨**。ただしschematic編集APIの制約は実在する。EasyEDA Proは有力な対抗候補で、単に「自動化できない」として除外できない。判断根拠と小規模な比較条件を後述する。

今回はauditに限定し、schematic/PCB/firmwareは変更していない。Rev.A資産も移動・複製していない。

### 調査の範囲

root/firmware/hardwareのREADME、docs全体の関連記述、GPIO/USB/CC/RGB実装、KiCad source・library tables・製造BOM、直近の設計変更commit、branch/tag、GitHub PR/issue一覧を確認した。vendored u8g2の全履歴やRev.A配線全体は追跡していない。既存validationとの重複を避けるため、隣接 `emiuet-validation` のREADME、validation matrix、VAL-CORE-01 READMEも確認した。

重要な変更は `2ad9825` (2026-08-31: Device-only)、`03ac33d` (2026-09-01: USB給電/RGB)、`1fff3fd` (2026-09-02: 製品思想・文書・CC7転用の修正)。ローカルtagはなく、[PR #3](https://github.com/emnyeca/emiuet/pull/3) はOPEN、#1/#2はMERGED。取得時のissue一覧は空。mainへのmerge有無を、ローカル設計の有無と混同しない。

## 2. 要件・判断の再構成

`CONFIRMED` は有効な意思決定または実ファイルで確認できた事実であり、実機合格を意味しない。`LIKELY` は推定、`LEGACY` は撤回済み設計、`CONFLICT` は不一致、`UNDECIDED` は未確定。IDは本audit内の追跡用であり、新たな仕様体系を導入したものではない。

| Requirement / Decision | Current interpretation | Status | Evidence | Conflicts | Action |
|---|---|---|---|---|---|
| MUS-01 配列・演奏 | 6×13、上方向PB、自動center、限定stringwise MPE | CONFIRMED | decisions §1–4、board_pins、matrix/input_router | schematicに実matrixなし | 78キー/diode回路を実装し演奏負荷で確認 |
| MUS-02 sliders/UX | PB/MOD/VELの3本、minimal OLED、button×3 | CONFIRMED | README、pinout、slider/controls/ui_oled | ADC filter/OLED接続がdraft注記 | analog値・機構・ノイズ合格条件を選定 |
| USB-01 | single USB-C、Device/UFP、MIDI＋HID composite、native flashing | CONFIRMED | decisions §7–8、midi_out_usb、J1/U1 | 保護・recovery回路未完 | USB/BOOTの実回路化 |
| HID-01 | TYPEは補助、4隅2秒、再列挙せず切替 | CONFIRMED | keyboard-mode、input_router | 実機統合は未検証 | 演奏/HID release境界を維持 |
| MIDI-01 | Type-A TRS OUT＋isolated IN、USB、BLE capability | CONFIRMED | decisions §6、UART/USB実装 | J2/J3/U5未接続、BLE stub | OUT/INを設計、BLE完成と宣伝しない |
| BLE-01 | BLE MIDI/Custom Servicesは将来実装を拘束する設計資料 | CONFIRMED / UNDECIDED | docs/BLE、midi_out_ble | normative記述に対しUUID等はplaceholder | 有効な方針を保ち、未確定protocolを別扱い |
| MCU-01 | ESP32-S3-MINI-1-N4R2、GPIO26不使用 | CONFIRMED | pinout、board_pins、U1、Espressif資料 | footprint未選定 | exact MPN・land pattern・antenna keepout照合 |
| PWR-01 | 外部USB 5V、内蔵battery/charging/PowerPathなし | CONFIRMED | decisions §8/11、sch部品構成、history | 旧PCB/BOMには電池系 | 旧電源を再採用しない |
| PWR-02 | 5V LED、3.3V MCU/OLED/logic、約1.5A製品上限 | CONFIRMED / UNDECIDED | decisions §8、U3候補 | regulator・保護・実電流未確定 | 負荷/温度/起動から選定、上限を定格保証と呼ばない |
| USB-02 CC | TUSB320固定UFP、attach/current検出、3Aでも1.5A上限 | CONFIRMED | decisions §9、tusb320、TI Rev.F §7.3.1.2 | error時予算更新とUSB状態連携なし | fault時縮退、Rp低下応答を設計 |
| RGB-01 | SK6812 MINI-E×78、GPIO38/AHCT、single chain | CONFIRMED | decisions §10、D1–D78、led_renderer | buffer等未接続、local bypassなし | 実回路/電流モデル/物理mappingを完成 |
| ADC-01 | ADC1 GPIO1/2/4、slider noise抑制 | CONFIRMED / UNDECIDED | pinout、slider、旧design notes §4 | RC/slider値未確定 | 許容noiseと応答時間を決める |
| PROT-01 | VBUS/CC/USB/外部端子の保護、inrush/短絡対策 | UNDECIDED | hardware README、sch注記 | 部品・配線が無い | exact partsと帰路をdatasheetから設計 |
| DBG-01 | GPIO0 boot、EN/reset、native USB recovery | CONFIRMED / UNDECIDED | pinout、旧notes §3、Espressif guide | 現行draftに必要周辺回路なし | EN/BOOTを実装しbad firmware復旧を確認 |
| MECH-01 | 薄型、78 low-profile keys | CONFIRMED / UNDECIDED | README、旧PCB/plate/topLeft/topRight | Rev.B外形寸法・層数・筐体拘束未確定 | 旧寸法を転記せずkey pitch/LED干渉/端子位置を確認 |
| MFG-01 | JLCPCB向け旧製造出力あり | LEGACY / UNDECIDED | production、hardware/bom | Rev.B BOM/PCBA・手実装境界なし | switch/hotswap/LED向き・実装面と調達を決定 |
| MFG-02 | Basic/Extended採用規則 | UNDECIDED | 現行decisions等に明示方針なし | 在庫・単価の監査未実施 | 安全/供給/総実装費で判断し、Basic優先を捏造しない |

## 3. 不一致と優先して解消するリスク

1. **READMEの「architecture draft」は正しいが、未完成範囲が小さく見える。** `Emiuet.kicad_sch` は87部品（LED78＋その他9）。matrix、slider、OLED、保護、reset/BOOT、各LED bypassは実回路になっていない。部品選定前に接続設計そのものが必要。
2. **電流制限を安全と呼べる根拠が不足。** `usb_power.c` はDefault/unknownをLED 200mA、1.5A/3Aを1000mAとする。sink attach状態を予算条件にせず、`tusb320.c` のread失敗時には前回値を保持する。`midi_out_usb.c` のdescriptor引数は250mAだが、MCU/OLED等を含む全機電流との対応がない。未列挙・configured・suspend・power-bank・Rp低下・I2C故障を区別した電力状態表が必要。USB適合はUNVERIFIED。
3. **LEDの計算値は実電流上限ではない。** `led_renderer.c` は60mA/pixelのRGB比例モデルで、idle電流、部品variant、過渡、MCU負荷を計測していない。電流モデルを実測で補い、fault時の縮退とhardware保護を合わせて設計する必要がある。
4. **PR #3本文は古い。** CC7をglobal brightnessへ転用すると書かれているが、`1fff3fd` の `led_control.c` とdecisionsでは撤回済み。PR本文を仕様根拠に戻さない。今回外部のPR本文は編集していない。
5. **GPIO正本の表現が重複。** pinout文書と `board_pins.h` の双方がsource of truthを名乗る。今回の割当値は一致するが、変更時はpinoutを設計割当、headerをその実装として区別し、schematic net/pinと照合する。
6. **履歴化で隠れた継続要件がある。** `history/rev-a-design-notes.md` のboot安定性、EN、ADC noise等は旧電池方式とは独立した設計根拠。旧revision名だけで廃止しない。`.github/copilot-instructions.md` のdocs一律優先、最小差分優先も、current/historyの区別と今回の再設計指示に照らして読む。
7. **再現性の障害。** `sym-lib-table` と `fp-lib-table` の一部が旧 `F:/…` 絶対パス。埋込symbolで開けることはlibraryが再現可能な証拠ではない。project-localまたはversion固定の共有libraryへ解決する必要がある。
8. **BLE資料の読者と言語。** docs/BLEはfirmware/app開発者向けだが英語で、normative方針とplaceholderが同居する。将来編集時に日本語へ整理し、有効な要件はhistoryへ落とさない。未完成BLEをPCB必須変更の理由にしない。

## 4. 既存hardwareの判定と独立検証

| 対象 | 分類 | 利用可能な範囲 |
|---|---|---|
| `hardware/kicad/Emiuet.kicad_sch` | Rev.B draft | USB給電/RGB/GPIOの意図。完成回路として流用不可 |
| `Emiuet_RevA.kicad_sch` | Rev.A legacy | 旧回路・機構を確認するときだけ参照 |
| `Emiuet.kicad_pcb`、main production、`hardware/bom/Emiuet_RevA_BOM.xlsx` | Rev.A legacy | 旧製造物。Rev.B発注不可 |
| plate/topLeft/topRightと各production | legacy機構参照 | Rev.Bへの適合はUNVERIFIED。部品変更/LED追加後に干渉確認 |
| `Emiuet.kicad_pro` / library tables | mixed | 現行schと旧PCBを同じprojectが指す。旧絶対library参照あり |

ファイル名だけでなく実体を確認した。旧PCB/BOMにはBQ24074、TPS61023、LM66100、battery、USB-C×2があり、現行schにはそれらがない。一方、Rev.B schにはTUSB320、78 LEDがあるため、全体をRev.Aと分類するのも誤り。

独立VerifierがKiCad **10.0.3** (`C:/Program Files/KiCad/10.0/bin/kicad-cli.exe`) で現行schのERCとnetlist exportを実行した。ERCは **FAIL: 50 errors / 174 warnings**。この件数には接続不備と配置上の警告が混在し、全てを同じ種類の電気故障とは数えない。重要なnetlist事実は次の通り。

- U3 regulatorの5端子が未接続。
- U4 bufferはinput pin 2とMCU pin 34の接続のみで、電源/GND/output等が未接続。D1 DINはundriven。
- U5の8端子、J2/J3 TRSの全端子が未接続。
- 非LED9部品のinstance footprintが空。matrix/UI/protection等は注記に留まる。

再現コマンド（出力先は任意の一時directory。project sourceは保存しない）:

```powershell
$kicadCli = 'C:/Program Files/KiCad/10.0/bin/kicad-cli.exe'
& $kicadCli sch erc --exit-code-violations --output "$env:TEMP/emiuet-audit-erc.rpt" hardware/kicad/Emiuet.kicad_sch
& $kicadCli sch export netlist --output "$env:TEMP/emiuet-audit.net" hardware/kicad/Emiuet.kicad_sch
```

Rev.B PCBが無いためRev.B DRC/parityはUNVERIFIED。旧PCBを更新して整合させる操作はしない。実機の電圧/温度/USB/EMI、footprint適合、firmware integration buildも本auditではUNVERIFIED。既存host testsだけでhardwareをPASSにしない。

## 5. EDA再評価

2026-10-05に一次資料を確認。以下は資料上の能力とこのprojectでの判断であり、EasyEDA/atopileを実機操作した比較ベンチマークではない。

| 評価軸 | KiCad 10 | EasyEDA Pro | atopile＋KiCad |
|---|---|---|---|
| AIによるschematic編集 | text構造へアクセス可能だが10のIPCはPCB Editorのみ。生成/編集後のnetlist・描画照合が必要 | 4.1.60以降のdesktop CLIからextension API、SCH/PCB/libraryへアクセス | `.ato`で接続/制約を記述。導入する言語とcompilerが増える |
| PCB操作 | IPC API＋GUI。10ではheadless IPCではない | PCB APIあり。editor/sessionへの依存を確認する | KiCad layoutを利用 |
| ERC/DRC/parity・CI | CLI ERC/DRC、schematic-parity、export。現在の環境でERC実行済み | schematic/PCB check API。clean runnerでの起動・保存・完了待ちを実証する必要 | build/constraints/checks＋KiCad DRC。通常ERCと同等と推定しない |
| Git/diff/人間review | text差分＋PDF/SVG＋netlist。UUID/座標差分だけでは読みにくい | local project/exportとtext `.eprj3`の手順あり。Git不可能ではないがround-trip差分を評価 | code差分は読める。生成物とコードの二重編集を避ける必要 |
| BOM/LCSC/JLCPCB | supplier field/CSV/position/Gerberを明示管理 | 部品library/製造連携が候補上の利点。MPN・pad適合を別途確認 | buildからBOM/製造出力。供給選定とversion固定を確認 |
| library/再現性 | project-local資産とtool version固定が可能 | local library/exportの完結性・offline復元を確認 | package/compiler/library固定が追加で必要 |
| lock-in/保守 | open format、既存閲覧/レビュー手段が利用可能 | vendor仕様とAPI変更への依存。local exportは軽減策 | open toolchainだがDSL/compilerへの依存が増える |
| 安全なAI編集 | APIまたは構造化編集、小単位差分、描画/netlist/ERCを合わせる | APIでも接続/保存/DRC/描画まで確認 | constraint通過だけで回路・layout安全を保証しない |

根拠: [KiCad 10 CLI](https://docs.kicad.org/10.0/en/cli/cli.html)、[IPC APIのversion別境界](https://dev-docs.kicad.org/en/apis-and-binding/ipc-api/for-addon-developers/)、[EasyEDA Pro CLI/API・local text project](https://prodocs.easyeda.com/en/api/guide/cli.html)、[local export](https://prodocs.easyeda.com/en/project/file-save-as-local/)、[atopile公式](https://github.com/atopile/atopile)。KiCad 11向けheadless IPCを10の機能として扱わない。

**推奨理由:** 本件では、人間が回路を監修できること、ローカルで再現できること、検証と製造出力を自動化できることの合計を優先する。KiCadはその検証経路を既に実行でき、schematic作成の制約はあるものの、全面移行を今すぐ選ぶ根拠は不足する。既存回路の保存価値を理由にしているわけではない。

次の設計着手時、電源/MCUの小ブロック一つを「AI作成→再読込→netlist/ERC→PDF→人間による接続変更」で試す。KiCadの編集・reviewコストが支配的なら、同じブロックをEasyEDA Proで比較する。判定項目は接続の一致、offline再現、安定したGit差分、BOM/footprint照合、所要手間。atopileは反復回路が増え、コード正本を人間が監修できる見込みが立った場合の候補に留める。

製造はKiCadからJLCPCB向け出力を生成する方式をまず選ぶ。EasyEDA変換を必須の中間工程にするとsymbol/footprint/net変換の照合負担が増える。hybridを採るなら製造用一方向exportに限定し、双方を編集正本にしない。

## 6. Rev.Bアーキテクチャの推奨

```text
USB-C ×1 ─ D+/D- protection ─ ESP32-S3 native USB (MIDI/HID/recovery)
  ├ CC1/CC2 ─ TUSB320 fixed UFP ─ I2C/current status ─ firmware budget
  └ VBUS ─ protection/inrush/current control ─ 5V ─ 78 RGB
                                                ├ AHCT buffer ← GPIO38
                                                └ 3.3V regulator ─ MCU/OLED/logic
MCU ─ 6×13 diode matrix / slider ADC×3 / buttons×3 / pilot LED
    ├ UART TX ─ compliant driver ─ Type-A TRS OUT
    └ UART RX ← isolated receiver ← Type-A TRS IN
```

Host/DRP/dual USB/battery/charger/boost/PowerPathは復活させない。native USBを使うため外部USB data controllerは不要。TUSB320はUSB data controllerではなく、78 LEDの給電予算に必要なCC detectorとして残す現行判断に理由がある。抵抗Rdだけに替えるには固定の低電力運用という別の製品判断が必要。

5V LEDを選んだ現行条件では3.3V rail一本への統一は推奨しない。3.3V regulatorは未選定としてLDOとbuckを比較する。LDOなら損失は `(5−3.3)×I`、例えば0.3Aで0.51Wとなるため、部品数だけで選ばず温度・電圧降下・radio peak・ADC noiseを評価する。これは計算例であり負荷実測ではない。

MIDI OUTは既存の5V driver方針を出発点にし、不要な段数を減らす。3.3V対応の標準回路が存在することと、MCU GPIOをそのままTRSへつなげてよいことは別。rail変更は[公式MIDI電気仕様](https://midi.org/5-pin-din-electrical-specs)とType-A割当、source/sink定格を照合してから判断する。INの絶縁を部品削減で失わない。

### 部品根拠を確定する順序

| 対象 | 現在の理由・代替 | 設計を確定する前の証拠 | 状態 |
|---|---|---|---|
| ESP32-S3-MINI-1-N4R2 | native USB/BLE/GPIO。module変更は配列・FWへ波及 | exact datasheet、land pattern、antenna、EN/BOOT、errata、電源peak | 方針CONFIRMED、実装UNVERIFIED |
| TUSB320 | current検出。代替は同等CC detectorまたは固定低電力/Rd案 | exact suffix/package、dead-battery/供給電圧、pull-up/strap、reset中挙動 | 方針CONFIRMED、接続/故障応答UNVERIFIED |
| 3.3V regulator | draftの候補値を採用品としない。LDO/buck比較 | peak負荷、熱、dropout、stability、推奨C、起動 | UNDECIDED |
| SK6812 MINI-E/AHCT | 78 key可視化と3.3→5V。選定variantの確認が必要 | メーカーdatasheetのpin向き/電流/timing/Vih、buffer OE/power-off挙動 | footprint/電流UNVERIFIED |
| USB保護/MIDI optocoupler等 | 回路用途を先に固定してMPNを比較 | ESD容量/耐圧/クランプ、CTR/遅延、抵抗電力、connector定格 | UNDECIDED |

一次資料: [ESP32-S3-MINI-1 datasheet](https://documentation.espressif.com/esp32-s3-mini-1_mini-1u_datasheet_en.html)、[ESP32-S3 hardware guide](https://docs.espressif.com/projects/esp-hardware-design-guidelines/en/latest/esp32s3/schematic-checklist.html)、[TUSB320 Rev.F datasheet](https://www.ti.com/lit/ds/symlink/tusb320.pdf)。TI §7.3.1.2は接続中の電流検出更新にperiodic I2C soft resetを要求しているが、現在の2秒周期と故障時処理まで合格とする根拠にはならない。Espressifの電源能力推奨をそのままUSB実消費電流と読み替えない。

未選定品の最新datasheet/guide/reference/errata/application note、JLCPCB/LCSC在庫は未確認。MPN選定時にメーカーURL・document revision・参照節・取得日、電気制約、代替、供給確認日を同じ部品記録へ残す。値・接続が決まるまではverifiedにしない。

## 7. AI workflowとrepositoryの移行案

新しいrequirements/architecture/datasheets等の空directoryを一括作成しない。`docs/decisions.md` は判断、`docs/pinout-v3.md` は割当、`hardware/kicad/` は電気設計、schematic fieldはMPN/値/footprint/LCSC、productionは生成物という既存構造を活かす。要求IDは給電、boot、MIDI、演奏latencyなど検証へ結び付く高影響項目からのみ導入する。

重要判断はdecisionsの該当節にcontext/options/chosen reason/consequencesを短く統合する。日付・根拠は判断の由来が必要な場合に記載し、各変更ごとの大量ADRは作らない。部品選定理由は次回の選定成果を一つのhardware設計ノートにまとめ、schematicと同じ値の表を手入力で複製しない。

1. **Designer:** 一つの回路ブロックをdatasheetから構成。接続、値、footprint、未決事項を明示し、schematicの見た目まで出す。
2. **Verifier:** 別agentがnetlist/pinout/電源/footprintを独立照合し、ERC/DRC結果とtool versionを記録。Designerの説明を根拠に代用しない。
3. **Reviewer:** 回路設計が間違っている可能性から、reset、帰路、ADC noise、ESD、USB、温度、製造を検討。少数の高影響指摘へ絞る。
4. **人間:** 製品方向と未決tradeoffを判断し、回路/PCBと測定結果を監修。自動チェック通過を製造承認にしない。

今回も別Verifierが実ファイルからERC/netlistを確認した。回路を設計した後の独立Reviewerは、次の設計反復で行う。役割を分けるためだけに常時3agentを走らせる必要はない。

自動化はKiCad version/library固定→ERC/netlist/PDF/BOM→新Rev.B PCBでDRC＋schematic-parity→Gerber/drill/positionという順。CIは元sourceを変更せず、tool version・commit・reportをartifact化する。FAILは検出違反、WARNは判断付き留保、UNVERIFIEDは未実行/証拠不足、PASSはその検査範囲の合格。未完成schematicのERCを無理に緑にするための一括除外はしない。

今回CIや新規test suiteは追加しない。監査段階では既存CLIを実行すれば足りる。保守対象の新規テストを導入するときはgovernance §4.3に従い、守る境界と追加しないリスクを提示する。

## 8. 物理validationとロードマップ

物理validationは既存の [emiuet-validation](https://github.com/emnyeca/emiuet-validation) のVAL-CORE-01とV0–V3を利用する。電池用試験を戻さず、新しい並列validation体系を作らない。validation boardのphysical power switchを、製品の確定要求へ自動昇格させない。

| 測定点/対象 | 目的・期待範囲の決め方 | 既存対応 | 今回の実測 |
|---|---|---|---|
| TP_USB_VBUS、TP_5V、遠端5V、GND | 入力/配電drop、inrush、負荷step。connector/LED/regulator条件から数値化 | V0-02、V2-05/06、V3-03 | 未測定 / UNVERIFIED |
| TP_3V3、電流測定用経路 | MCU peak時の電圧/温度、全機電流予算 | V0-02、V3-06 | 未測定 / UNVERIFIED |
| EN/BOOT | 立上り、通常boot、download、bad firmware復旧 | V0-04/05/06 | 未測定 / UNVERIFIED |
| CC1/CC2、I2C | attach、Rp低下、通信故障、reset中の予算 | V1-06/07、V2-04 | 未測定 / UNVERIFIED |
| USB D+/D- | 列挙/波形/復旧。測定用stubを増やさず適切にprobe | V1-01、V3-04 | 未測定 / UNVERIFIED |
| LED data 3V3/5V、first/last pixel | Vih/timing、mapping、供給変動 | V2-01/02、V3-02 | 未測定 / UNVERIFIED |
| matrix/ADC/UART/OLED | 同時負荷でscan/sliderノイズ/MIDI電気条件/I2C安定性 | V1、V3-01/05/06 | 未測定 / UNVERIFIED |

期待値の数値が未決の試験は、通電前にdatasheet限界と製品の許容latency/noiseから範囲を確定する。既存results templateへdesign value、expected range、measured value、PASS/FAIL、基板/BOM/FW commit、電源/ケーブル、測定器、波形を戻す。6 LEDでの合格を78 LED配電の合格と扱わない。

| 順序 | 実行内容 | 次へ進む条件 |
|---|---|---|
| 1 | EDAの小ブロック作成・再読込実証、library絶対パス解消 | 人間が接続を読め、clean環境で再現可能 |
| 2 | USB全機電力状態表、regulator/保護/MIDI部品選定、機構拘束確認 | 未列挙/suspend/Rp低下/fault時の挙動と予算、MPN根拠が揃う |
| 3 | Rev.B schematicを少数ブロックで実装。FWの予算状態を整合 | independent review、ERC、netlist/GPIO/footprint照合 |
| 4 | VAL-CORE-01で電源/MCU/I/O/RGBを確認 | V0–V2の合否と数値が記録される |
| 5 | Rev.B PCBを新設計、78 key/LEDの機構・帰路・熱を確認 | DRC/parity、antenna/USB/ADC/配電review、BOM/DFM |
| 6 | 製造出力と試作、V3統合確認 | 同一commitから出力、実測で性能・安全境界を確認 |

アムニェカさんの判断が必要なのは、EDA変更の必要性が実証された場合の選択、Rev.B外形/層数/実装コストのtradeoff、選定後の給電条件と許容輝度である。現行single USB給電方針の再承認やRev.A全保存の承認を、今回の前進条件にはしない。

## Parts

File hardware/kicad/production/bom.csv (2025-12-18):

Designator | Footprint | Quantity | Value | LCSC Part #
BRD2 | 9E6018AD | 1 | waveshare0.96inch
BT1 | Battery Cell 800mah bis | 1 | 800mAh
C1, C12 | 0603 | 2 | 1μ
C10 | 0603 | 1 | 33p
C11, C13, C15, C16, C17, C18, C19, C20, C22, C25, C27, C30, C5, C8, C9 | 0603 | 15 | 100n
C14, C21, C23, C24, C28, C29, C3, C4, C6, C7 | 0603 | 10 | 22μ
C2 | 0603 | 1 | 10μ
C26 | 0603 | 1 | Byp or Bulk xμ_10μ
D1 | D_SOD-123F_noSilk | 1 | SMF5V0A
D1_0, D1_1, D1_10, D1_11, D1_12, D1_2, D1_3, D1_4, D1_5, D1_6, D1_7, D1_8, D1_9, D2_0, D2_1, D2_10, D2_11, D2_12, D2_2, D2_3, D2_4, D2_5, D2_6, D2_7, D2_8, D2_9, D3_0, D3_1, D3_10, D3_11, D3_12, D3_2, D3_3, D3_4, D3_5, D3_6, D3_7, D3_8, D3_9, D4_0, D4_1, D4_10, D4_11, D4_12, D4_2, D4_3, D4_4, D4_5, D4_6, D4_7, D4_8, D4_9, D5_0, D5_1, D5_10, D5_11, D5_12, D5_2, D5_3, D5_4, D5_5, D5_6, D5_7, D5_8, D5_9, D6_0, D6_1, D6_10, D6_11, D6_12, D6_2, D6_3, D6_4, D6_5, D6_6, D6_7, D6_8, D6_9 | D_SOD-123_no silks | 78 | 1N4148
D3 | LED_D5.0mm THT Turn_noSilk | 1 | LED B
F1, F2 | 1812 | 2 | MF-MSMF110-2
FB1, FB2 | 0805 | 2 | FerriteBead_Small
J1, J2 | USB_C_Receptacle_G-Switch_GT-USB-7010ASV_noSilk | 2 | USB_C_Receptacle_USB2.0_16P
J3 | Jack_3.5mm_KoreanHropartsElec_PJ-313D-4A_Horizontal | 1 | AudioJack3
J4 | JST_PH_B2B-PH-SM4-TB_1x02-1MP_P2.00mm_Vertical_right+ | 1 | Conn_01x02_Pin
JP1 | TestPoint_2Pads_Pitch2.54mm_Drill0.8mm | 1 | Jumper_2_Bridged
JP3 | SolderJumper-2_P1.3mm_Bridged_RoundedPad1.0x1.5mm | 1 | Jumper_2_Bridged
L1 | L_CommonModeChoke_Coilcraft_0603USB_noSilk | 1 | DLW21SN900SQ2L
L2 | L_TDK_VLS6045EX_VLS6045AF_noSilk | 1 | 4.7μ
Q1 | SOT-23_noSilk | 1 | S9013 J3
R1, R10, R25, R26 | 0603 | 4 | 10k
R11 | 0603 | 1 | 900k
R12, R17, R18 | 0603 | 3 | 4.7k
R13 | 0603 | 1 | 887k
R14 | 0603 | 1 | 120k
R15 | 1206 | 1 | 200k
R16 | 0603 | 1 | 200k
R19, R20, R21 | 0603 | 3 | 100
R2, R3 | 0603 | 2 | 5.1k
R22 | 0603 | 1 | 1.18k
R23 | 0603 | 1 | 4.12k
R24 | 0603 | 1 | 1.13k
R27 | R_Axial_DIN0204_L3.6mm_D1.6mm_P7.62mm_Horizontal | 1 | 560k
R28 | 0603 | 1 | 1k
R29 | 0603 | 1 | 220k
R4, R9 | 0603 | 2 | 220
R5 | R_Axial_DIN0204_L3.6mm_D1.6mm_P7.62mm_Horizontal | 1 | 1k
RV1, RV2, RV3 | Potentiometer_Slider_AliExpress_10k_35mm | 3 | 10k
SW1 | SW_SK22D02_DPDT_Angled | 1 | SW_Slide_DPDT
SW1_0, SW1_1, SW1_10, SW1_11, SW1_12, SW1_2, SW1_3, SW1_4, SW1_5, SW1_6, SW1_7, SW1_8, SW1_9, SW2_0, SW2_1, SW2_10, SW2_11, SW2_12, SW2_2, SW2_3, SW2_4, SW2_5, SW2_6, SW2_7, SW2_8, SW2_9, SW3_0, SW3_1, SW3_10, SW3_11, SW3_12, SW3_2, SW3_3, SW3_4, SW3_5, SW3_6, SW3_7, SW3_8, SW3_9, SW4_0, SW4_1, SW4_10, SW4_11, SW4_12, SW4_2, SW4_3, SW4_4, SW4_5, SW4_6, SW4_7, SW4_8, SW4_9, SW5_0, SW5_1, SW5_10, SW5_11, SW5_12, SW5_2, SW5_3, SW5_4, SW5_5, SW5_6, SW5_7, SW5_8, SW5_9, SW6_0, SW6_1, SW6_10, SW6_11, SW6_12, SW6_2, SW6_3, SW6_4, SW6_5, SW6_6, SW6_7, SW6_8, SW6_9 | SW_Hotswap_Kailh_Choc_noD_reflect | 78 | Switch_SW_Push
SW2 | Akidsuki_WhiteCircleTactileSwitch | 1 | SW_SPST
SW3, SW4 | SW_PUSH_6mm_H9.5mm_DTS65 | 2 | SW_SPST
TH1 | 0603 | 1 | Thermistor
U1 | ESP32-S2-MINI-1_thermalVia_noSilk | 1 | ESP32-S3-MINI-1
U2 | Texas_DRT-3_noSilk | 1 | TPD2EUSB30ADRTR
U3 | SOT-363_SC-70-6_noSilk | 1 | LM66100DCK
U4 | SOT-23_noSilk | 1 | AP7333-33SAG-7
U5 | Texas_X2QFN-12_1.6x1.6mm_P0.4mm_noSilk | 1 | TUSB320LAIRWBR
U6 | SOT-563_noSilk | 1 | TPS61023DRLR
U7 | BQ24074_QFN-16_3x3mm_withThermalVia_noSilk | 1 | BQ24074RGT

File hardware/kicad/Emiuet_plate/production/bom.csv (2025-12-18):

Designator | Footprint | Quantity | Value | LCSC Part #
BRDC1 | 9E6018AD_Cutout | 1 | ~
DC1 | LED_D5.0mm THT Hole | 1 | ~
RVC1, RVC2, RVC3 | Potentiometer_Slider_AliExpress_10k_35mm_Hole | 3 | ~
SWC1 | Akidsuki_WhiteCircleTactileSwitch_Cutout | 1 | ~
SWC1_0, SWC1_1, SWC1_10, SWC1_11, SWC1_12, SWC1_2, SWC1_3, SWC1_4, SWC1_5, SWC1_6, SWC1_7, SWC1_8, SWC1_9, SWC2_0, SWC2_1, SWC2_10, SWC2_11, SWC2_12, SWC2_2, SWC2_3, SWC2_4, SWC2_5, SWC2_6, SWC2_7, SWC2_8, SWC2_9, SWC3_0, SWC3_1, SWC3_10, SWC3_11, SWC3_12, SWC3_2, SWC3_3, SWC3_4, SWC3_5, SWC3_6, SWC3_7, SWC3_8, SWC3_9, SWC4_0, SWC4_1, SWC4_10, SWC4_11, SWC4_12, SWC4_2, SWC4_3, SWC4_4, SWC4_5, SWC4_6, SWC4_7, SWC4_8, SWC4_9, SWC5_0, SWC5_1, SWC5_10, SWC5_11, SWC5_12, SWC5_2, SWC5_3, SWC5_4, SWC5_5, SWC5_6, SWC5_7, SWC5_8, SWC5_9, SWC6_0, SWC6_1, SWC6_10, SWC6_11, SWC6_12, SWC6_2, SWC6_3, SWC6_4, SWC6_5, SWC6_6, SWC6_7, SWC6_8, SWC6_9 | SW_Kailh_Choc_Cutout_YushadoCap | 78 | ~
SWC2, SWC3 | SW_PUSH_6mm_H9.5mm_DTS65_cutout | 2 | ~

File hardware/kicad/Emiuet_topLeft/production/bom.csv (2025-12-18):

Designator | Footprint | Quantity | Value | LCSC Part #
DC1 | LED_D5.0mm THT Hole_top | 1 | ~

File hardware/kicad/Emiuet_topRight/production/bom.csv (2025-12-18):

Designator | Footprint | Quantity | Value | LCSC Part #
BRDC1 | 9E6018AD_Cutout_top | 1 | ~
RVC1, RVC2, RVC3 | Potentiometer_Slider_AliExpress_10k_35mm_Top | 3 | ~
SWC1 | Akidsuki_WhiteCircleTactileSwitch_Cutout_top | 1 | ~
SWC2, SWC3 | SW_PUSH_6mm_H9.5mm_DTS65_cutout_top | 2 | ~

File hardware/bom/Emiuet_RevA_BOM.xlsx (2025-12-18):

Comment | Designator | Footprint | JLCPCB Part #（optional）
1μ | C1,C12 | 0603 | C15849
10μ | C2,C26 | 0603 | C19702
33p | C10 | 0603 | C1663
100n | C11,C13,C15,C16,C17,C18,C19,C20,C22,C25,C27,C5,C8,C9,C30 | 0603 | C14663
22μ | C14,C21,C23,C24,C3,C4,C6,C7,C28,C29 | 0603 | C59461
SMF5V0A | D1 | D_SOD-123F_noSilk | C193402
1N4148 | D1_0,D1_1,D1_10,D1_11,D1_12,D1_2,D1_3,D1_4,D1_5,D1_6,D1_7,D1_8,D1_9,D2_0,D2_1,D2_10,D2_11,D2_12,D2_2,D2_3,D2_4,D2_5,D2_6,D2_7,D2_8,D2_9,D3_0,D3_1,D3_10,D3_11,D3_12,D3_2,D3_3,D3_4,D3_5,D3_6,D3_7,D3_8,D3_9,D4_0,D4_1,D4_10,D4_11,D4_12,D4_2,D4_3,D4_4,D4_5,D4_6,D4_7,D4_8,D4_9,D5_0,D5_1,D5_10,D5_11,D5_12,D5_2,D5_3,D5_4,D5_5,D5_6,D5_7,D5_8,D5_9,D6_0,D6_1,D6_10,D6_11,D6_12,D6_2,D6_3,D6_4,D6_5,D6_6,D6_7,D6_8,D6_9 | D_SOD-123_nosilks | C85057
MF-MSMF110-2 | F1,F2 | 1812 | C89647
FerriteBead_Small | FB1,FB2 | 0805 | C1015
DLW21SN900SQ2L | L1 | L_CommonModeChoke_Coilcraft_0603USB_noSilk | C97856
4.7μ | L2 | L_APV_ANR5045_noSilk | C307880
S9013J3 | Q1 | SOT-23_noSilk | C6749
10k | R1,R10,R25,R26 | 0603 | C25804
5.1k | R2,R3 | 0603 | C23186
220 | R4,R9 | 0603 | C22962
900k | R11 | 0603 | C246015
887k | R13 | 0603
4.7k | R12,R17,R18 | 0603 | C23162
120k | R14 | 0603 | C25808
200k | R15 | 1206 | C17954
200k | R16 | 0603 | C25811
100 | R19,R20,R21 | 0603 | C22775
1.18k | R22 | 0603 | C170447
4.12k | R23 | 0603 | C2960702
1.13k | R24 | 0603 | C22833
1k | R28 | 0603 | C21190
220k | R29 | 0603 | C22961
Thermistor | TH1 | 0603 | C13564
ESP32-S3-MINI-1 | U1 | ESP32-S2-MINI-1_thermalVia_noSilk | C3013941
TPD2EUSB30ADRTR | U2 | Texas_DRT-3_noSilk | C94934
LM66100DCK | U3 | SOT-363_SC-70-6_noSilk | C2869734
AP7333-33SAG-7 | U4 | SOT-23_noSilk | C150746
TUSB320LAIRWBR | U5 | Texas_X2QFN-12_1.6x1.6mm_P0.4mm_noSilk | C132554
TPS61023DRLR | U6 | SOT-563_noSilk | C919459
BQ24074RGT | U7 | BQ24074_QFN-16_3x3mm_withThermalVia_noSilk | C54313

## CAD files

firmware/components/u8g2/sys/arduino/u8g2_full_buffer/SwitchBox/board.dxf
60
40
52
8
24
80
30
32
25
100
190
4
12
6
14

firmware/components/u8g2/sys/arm/stm32l031x6/clock.dxf
65
32
28
16
Draufsicht
Vorderansicht
von unten
von rechts
von links
14
6
45
60
30
20
8
35
75
55
10
12

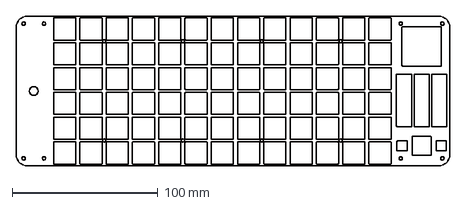
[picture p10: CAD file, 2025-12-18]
hardware/kicad/Emiuet_plate/Graphics/Emiuet_plate_edgecut dfx.dxf
297.0 x 102.4 mm

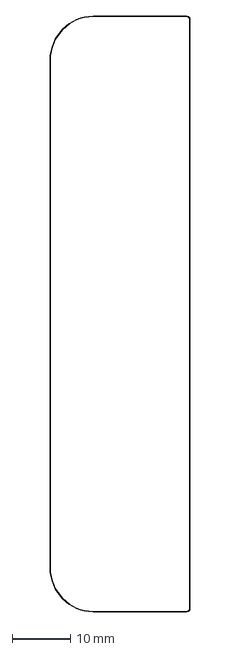
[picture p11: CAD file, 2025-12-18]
hardware/kicad/Emiuet_topLeft/Graphics/Emiuet_topLeft_edgecut dfx.dxf
24.0 x 102.4 mm

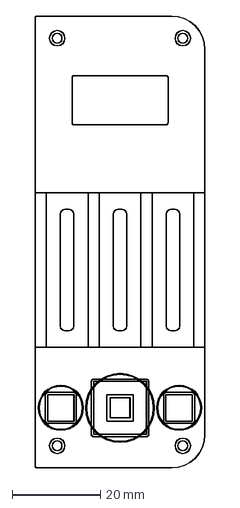
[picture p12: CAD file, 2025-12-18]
hardware/kicad/Emiuet_topRight/Graphics/Emiuet_topRight_Fab dfx.dxf
38.5 x 102.4 mm

firmware/components/u8g2/sys/arm/stm32l031x6/clock_2.dxf
65
Draufsicht
Vorderansicht
von unten
von rechts
von links
14
30
32
35
75
55
10
12
16
11
22
34
28
29
18
93
19
43
15
68
60
57
150
Holzbohrer: 2.5, 8, 10, 12, 16, 32mm
8
7
6
2.5mm

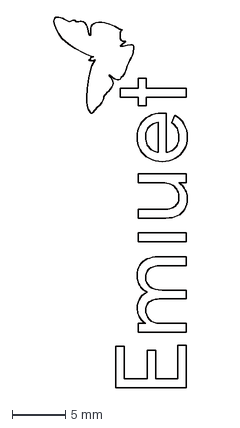
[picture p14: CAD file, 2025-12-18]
hardware/kicad/Emiuet_topLeft/Graphics/Emiuet_topLeft_mask dfx.dxf
12.7 x 35.0 mm

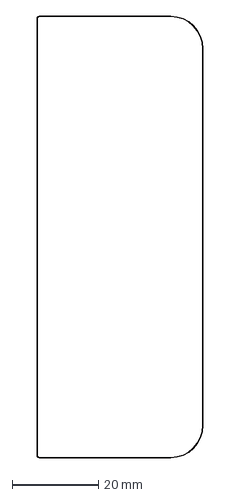
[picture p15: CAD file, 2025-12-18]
hardware/kicad/Emiuet_topRight/Graphics/Emiuet_topRight_edgecut dfx.dxf
38.5 x 102.4 mm

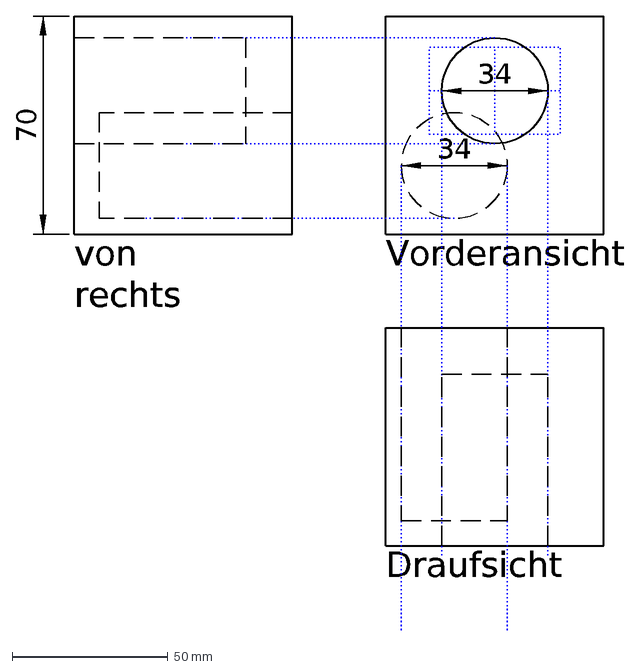
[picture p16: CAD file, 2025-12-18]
firmware/components/u8g2/sys/arm/stm32l031x6/clock_cube.dxf
Draufsicht
Vorderansicht
von rechts
70
34

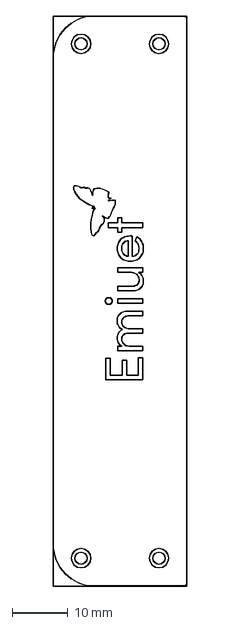
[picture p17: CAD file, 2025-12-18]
hardware/kicad/Emiuet_topLeft/Graphics/Emiuet_topLeft dfx.dxf
24.0 x 102.4 mm

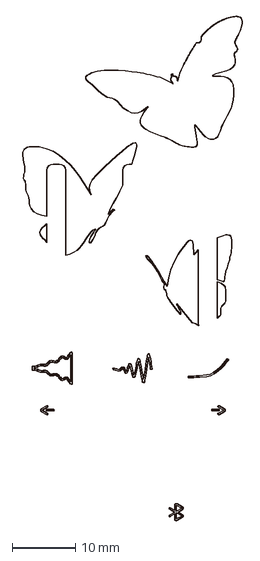
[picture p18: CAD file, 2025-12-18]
hardware/kicad/Emiuet_topRight/Graphics/Emiuet_topRight_Mask dfx.dxf
36.0 x 79.8 mm

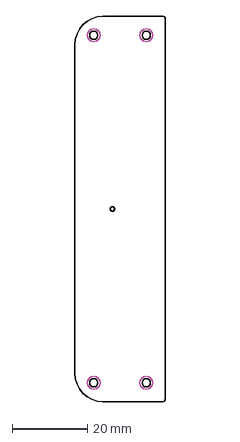
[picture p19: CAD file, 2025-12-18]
hardware/kicad/Emiuet_topLeft/Graphics/Emiuet_topLeft_Fab dfx.dxf
24.0 x 102.4 mm

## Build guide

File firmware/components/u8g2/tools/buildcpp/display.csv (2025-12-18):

# 1. device name
# 2. pinset
# 3. constructor name w/o prefix
u8x8_d_ssd1306_128x64_noname | 4WSWSPI | SSD1306_128X64_4W_SW_SPI
u8x8_d_ssd1306_128x64_noname | 4WHWSPI | SSD1306_128X64_4W_HW_SPI
u8x8_d_ssd1306_128x64_noname | 3WSWSPI | SSD1306_128X64_3W_SW_SPI
u8x8_d_ssd1306_128x64_noname | SSDSWI2C | SSD1306_128X64_SW_I2C
u8x8_d_ssd1306_128x64_noname | 6800 | SSD1306_128X64_6800
u8x8_d_ssd1306_128x64_noname | 8080 | SSD1306_128X64_8080

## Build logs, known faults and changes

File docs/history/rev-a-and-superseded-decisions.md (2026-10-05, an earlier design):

# Rev.Aおよび撤回済み判断

> **Historical / not current:** この文書は、現在のRev.Bで撤回された設計判断だけを記録します。Emiuetの現行product identityと設計判断は `../decisions.md` が正本です。

## Rev.A internal battery and PowerPath

Rev.Aはsingle-cell Li-ion battery、BQ24074 charger/PowerPath、battery NTC、BAT_VSENSE、TPS61023 5 V boostを内蔵し、充電中も動作するself-contained battery instrumentを目指していました。

Rev.Bではexternal USB 5 V onlyへ移行したため、このpower architectureとbattery validationは撤回されました。

## Rev.A dual USB

Rev.Aはcharging/power用USB-Cとdata用USB-Cを分離していました。data側にはinternal 5 VからLM66100を介したHost VBUS source pathも存在しました。

Rev.Bではsingle USB-C Device/UFPへ統合し、charging-only port、Host VBUS path、dual USB interactionを撤回しました。

## 旧Rev.B self-powered USB案

internal batteryを維持したままdata USB VBUSをpresence senseだけにするself-powered USB Device案がありました。この案ではseparate VBUS monitor GPIOとdetach handlingが必要でした。

Rev.BはUSB VBUSで本体そのものを給電するため、このself-powered monitor案を撤回しました。

## TUSB320によるCC/current検出

旧Rev.BではTUSB320（PORT=L、ADDR=L、I2C）をUFP attach/orientation/current detectorとして残していました。それ以前の「Rdだけに置き換えてTUSB320を削除する案」は、78 RGB LEDs追加後にSource current advertisementを取得する必要が生じたため一度撤回されていました。

TUSB320はCURRENT_MODE_DETECTをattach時に一度だけ更新し、接続中のRp変化はperiodic I2C soft reset（最大95 ms）と再debounce（133 ms）を経ないと反映できません（TI Rev.F §6.7、§7.3.1.2）。Type-C sinkのtSinkAdj（最大60 ms）を満たせず、reset中はRGBが周期消灯するため、2026-10-05にRd＋comparatorによる常時検出へ置換しました。TUSB320LAIもdatasheet上は同じ一回検出のため代替にしていません。

## 記録を残す理由と終了条件

これらはRev.A schematic/PCBを読む際に、現行Rev.Bとの違いを誤認しないために残します。Rev.A manufacturing dataをrepositoryから除去する判断が行われた場合、この文書もcommit historyだけへ移行できます。

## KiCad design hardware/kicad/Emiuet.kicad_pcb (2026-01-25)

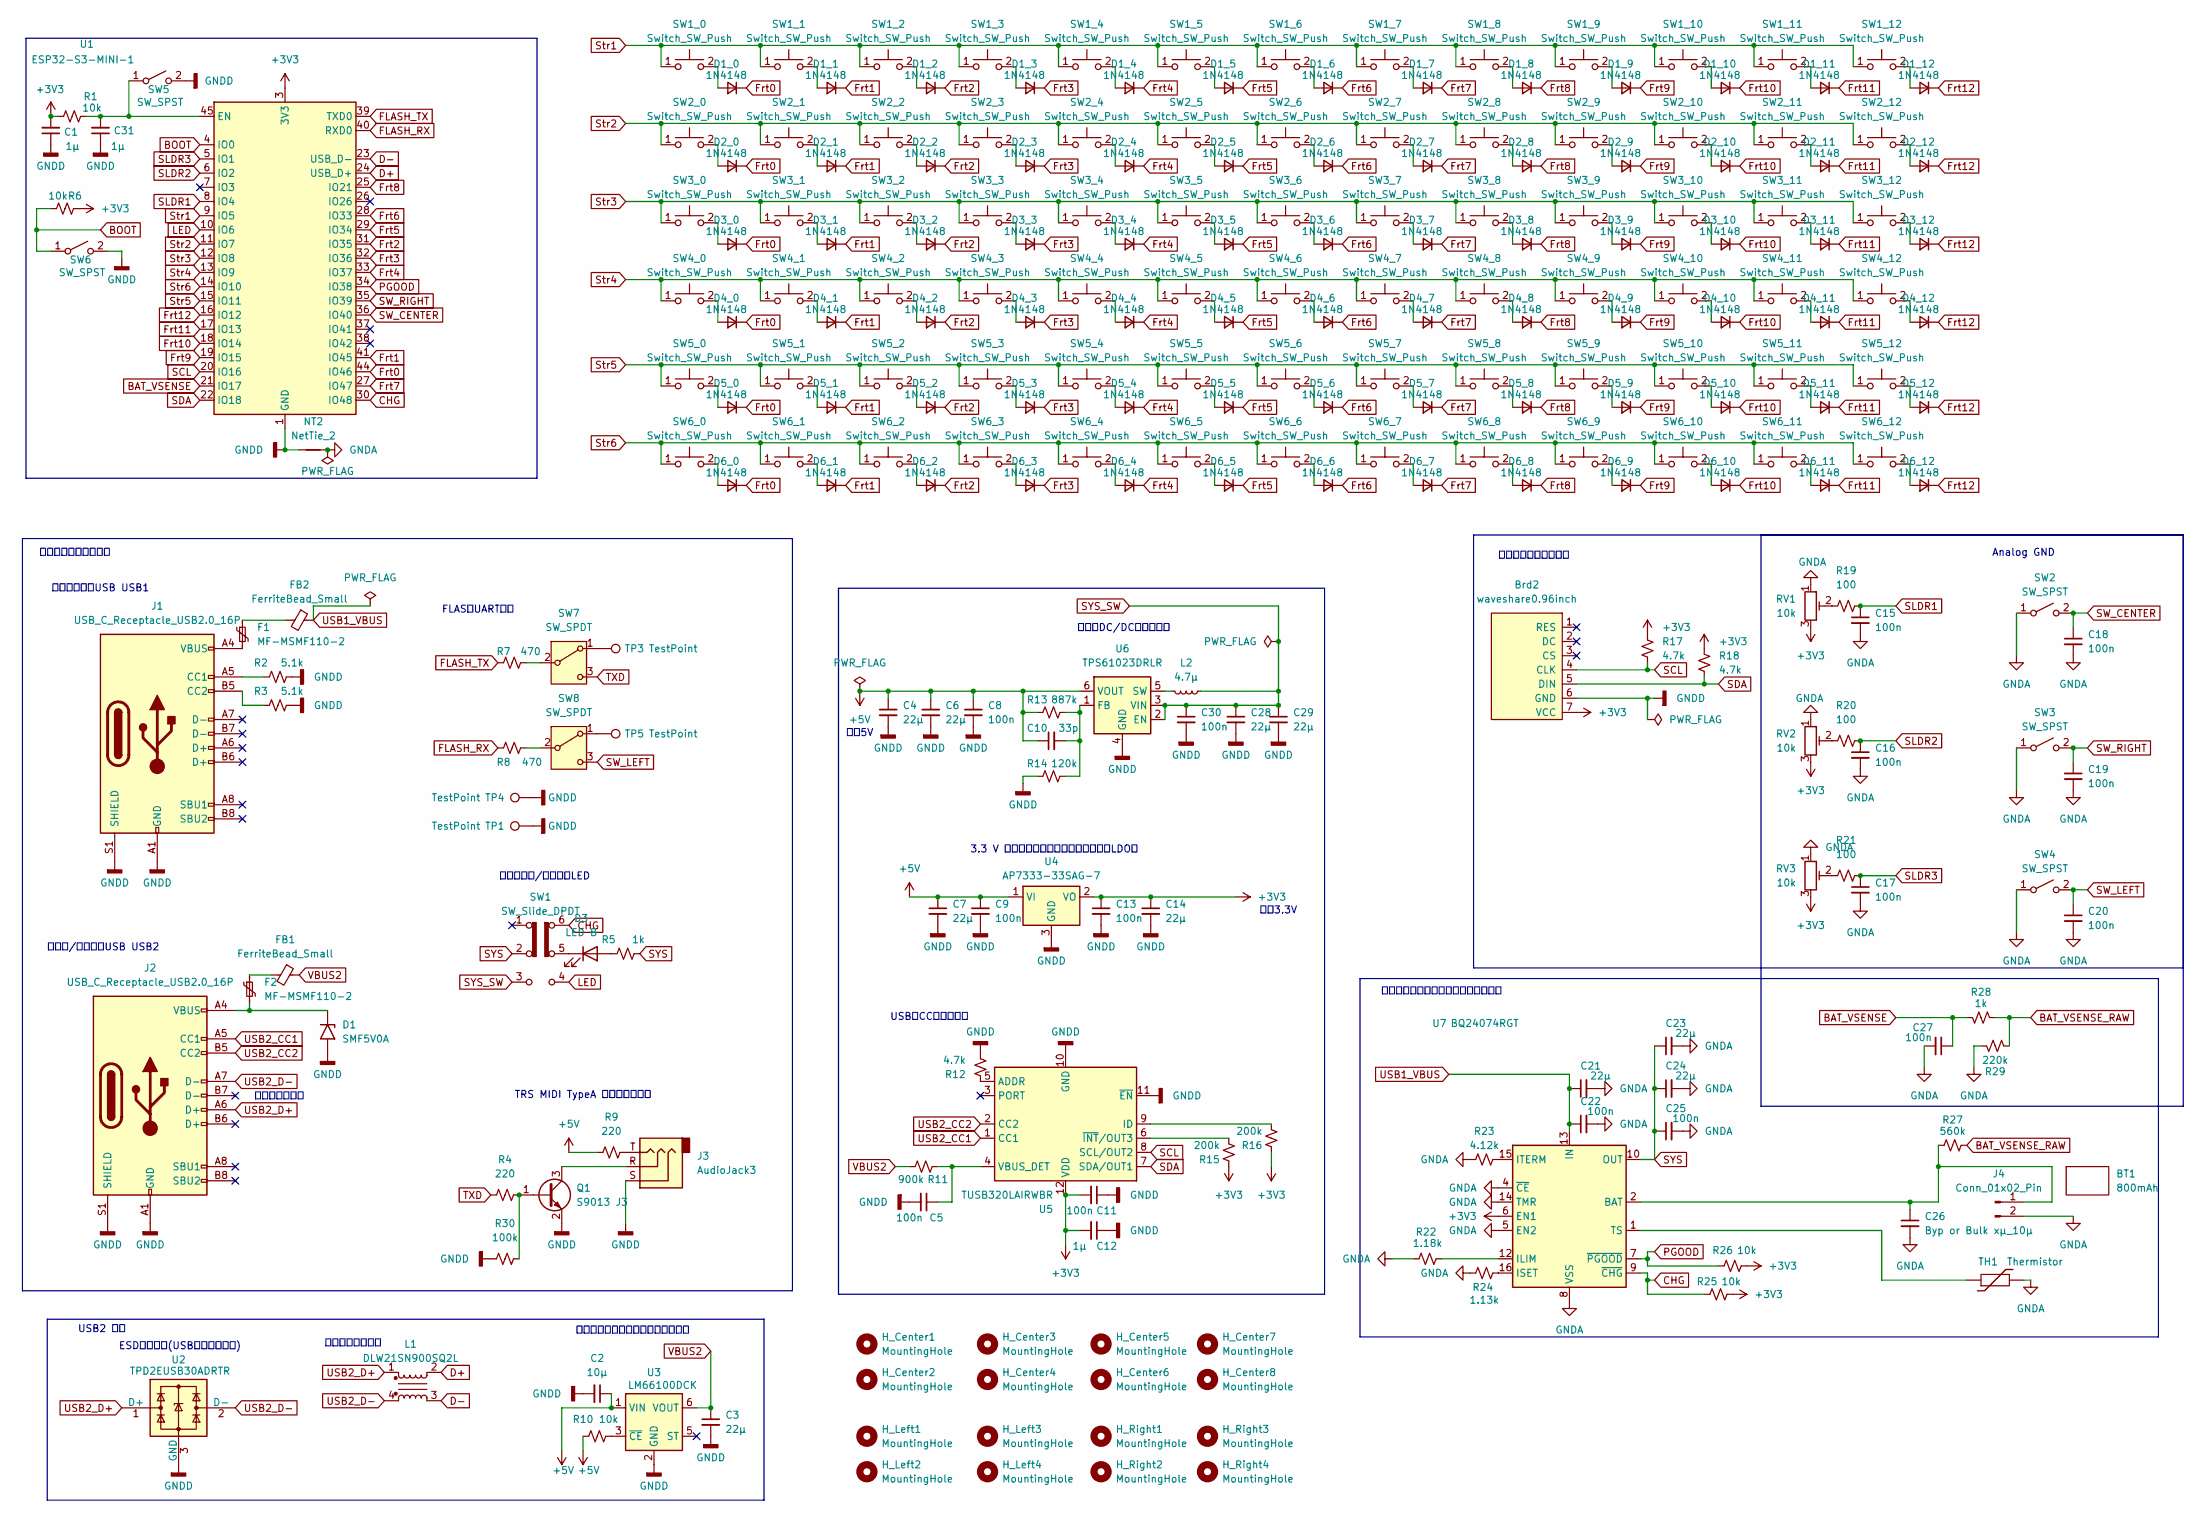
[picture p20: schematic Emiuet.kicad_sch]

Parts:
BT1: 800mAh; Battery Cell 800mah nobis
Brd2: waveshare0.96inch; 9E6018AD
C1, C12, C31: 1μ; C_0603_1608Metric_noSilks
C2: 10μ; C_0603_1608Metric_noSilks
C3, C4, C6, C7, C14, C21, C23, C24, C28, C29: 22μ; C_0603_1608Metric_noSilks
C5, C8, C9, C11, C13, C15, C16, C17, C18, C19, C20, C22, C25, C27, C30: 100n; C_0603_1608Metric_noSilks
C10: 33p; C_0603_1608Metric_noSilks
C26: Byp or Bulk xμ_10μ; C_0603_1608Metric_noSilks
D1: SMF5V0A; D_SOD-123F_noSilk
D1_0, D1_1, D1_2, D1_3, D1_4, D1_5, D1_6, D1_7, D1_8, D1_9, D1_10, D1_11, D1_12, D2_0, D2_1, D2_2, D2_3, D2_4, D2_5, D2_6, D2_7, D2_8, D2_9, D2_10, D2_11, D2_12, D3_0, D3_1, D3_2, D3_3, D3_4, D3_5, D3_6, D3_7, D3_8, D3_9, D3_10, D3_11, D3_12, D4_0, D4_1, D4_2, D4_3, D4_4, D4_5, D4_6, D4_7, D4_8, D4_9, D4_10, D4_11, D4_12, D5_0, D5_1, D5_2, D5_3, D5_4, D5_5, D5_6, D5_7, D5_8, D5_9, D5_10, D5_11, D5_12, D6_0, D6_1, D6_2, D6_3, D6_4, D6_5, D6_6, D6_7, D6_8, D6_9, D6_10, D6_11, D6_12: 1N4148; D_SOD-123_no silks
D3: LED B; LED_D5.0mm THT Turn_noSilk
F1, F2: MF-MSMF110-2; Fuse_1812_4532Metric_noSilk
FB1, FB2: FerriteBead_Small; L_0805_2012Metric_noSilk
H_Center1, H_Center2, H_Center3, H_Center4, H_Center5, H_Center6, H_Center7, H_Center8: MountingHole; MountingHole_2.2mm_M2_jlcpcb
H_Left1, H_Left2, H_Left3, H_Left4: MountingHole; MountingHole_2.2mm_M2_jlcpcb
H_Right1, H_Right2, H_Right3, H_Right4: MountingHole; MountingHole_2.2mm_M2_jlcpcb
J1, J2: USB_C_Receptacle_USB2.0_16P; USB_C_Receptacle_G-Switch_GT-USB-7010ASV_noSilk
J3: AudioJack3; Jack_3.5mm_KoreanHropartsElec_PJ-313D-4A_Horizontal
J4: Conn_01x02_Pin; JST_PH_B2B-PH-SM4-TB_1x02-1MP_P2.00mm_Vertical_right+
L1: DLW21SN900SQ2L; L_CommonModeChoke_Coilcraft_0603USB_noSilk
L2: 4.7μ; L_TDK_VLS6045EX_VLS6045AF_noSilk
NT2: NetTie_2; NetTie-2_SMD_Pad0.5mm
Q1: S9013 J3; SOT-23_noSilk
R1, R6, R10, R25, R26: 10k; R_0603_1608Metric_noSilks
R2, R3: 5.1k; R_0603_1608Metric_noSilks
R4, R9: 220; R_0603_1608Metric_noSilks
R5: 1k; R_Axial_DIN0204_L3.6mm_D1.6mm_P7.62mm_Horizontal
R7, R8: 470; R_0603_1608Metric_noSilks
R11: 900k; R_0603_1608Metric_noSilks
R12, R17, R18: 4.7k; R_0603_1608Metric_noSilks
R13: 887k; R_0603_1608Metric_noSilks
R14: 120k; R_0603_1608Metric_noSilks
R15: 200k; R_1206_3216Metric_noSilk
R16: 200k; R_0603_1608Metric_noSilks
R19, R20, R21: 100; R_0603_1608Metric_noSilks
R22: 1.18k; R_0603_1608Metric_noSilks
R23: 4.12k; R_0603_1608Metric_noSilks
R24: 1.13k; R_0603_1608Metric_noSilks
R27: 560k; R_Axial_DIN0204_L3.6mm_D1.6mm_P7.62mm_Horizontal
R28: 1k; R_0603_1608Metric_noSilks
R29: 220k; R_0603_1608Metric_noSilks
R30: 100k; R_0603_1608Metric_noSilks
RV1, RV2, RV3: 10k; Potentiometer_Slider_AliExpress_10k_35mm
SW1: SW_Slide_DPDT; SW_SK22D02_DPDT_Angled
SW1_0, SW1_1, SW1_2, SW1_3, SW1_4, SW1_5, SW1_6, SW1_7, SW1_8, SW1_9, SW1_10, SW1_11, SW1_12, SW2_0, SW2_1, SW2_2, SW2_3, SW2_4, SW2_5, SW2_6, SW2_7, SW2_8, SW2_9, SW2_10, SW2_11, SW2_12, SW3_0, SW3_1, SW3_2, SW3_3, SW3_4, SW3_5, SW3_6, SW3_7, SW3_8, SW3_9, SW3_10, SW3_11, SW3_12, SW4_0, SW4_1, SW4_2, SW4_3, SW4_4, SW4_5, SW4_6, SW4_7, SW4_8, SW4_9, SW4_10, SW4_11, SW4_12, SW5_0, SW5_1, SW5_2, SW5_3, SW5_4, SW5_5, SW5_6, SW5_7, SW5_8, SW5_9, SW5_10, SW5_11, SW5_12, SW6_0, SW6_1, SW6_2, SW6_3, SW6_4, SW6_5, SW6_6, SW6_7, SW6_8, SW6_9, SW6_10, SW6_11, SW6_12: Switch_SW_Push; SW_Hotswap_Kailh_Choc_noD_reflect
SW2: SW_SPST; Akidsuki_WhiteCircleTactileSwitch
SW3, SW4: SW_SPST; SW_PUSH_6mm_H9.5mm_DTS65
SW5, SW6: SW_SPST; SW_SPST_TS-1088-xR020
SW7, SW8: SW_SPDT; SW_SPDT_Shouhan_MSK12C02
TH1: Thermistor; R_0603_1608Metric_noSilks
TP1, TP3, TP4, TP5: TestPoint; TestPoint_Pad_D1.0mm
U1: ESP32-S3-MINI-1; ESP32-S2-MINI-1_thermalVia_noSilk
U2: TPD2EUSB30ADRTR; Texas_DRT-3_noSilk
U3: LM66100DCK; SOT-363_SC-70-6_noSilk
U4: AP7333-33SAG-7; SOT-23_noSilk
U5: TUSB320LAIRWBR; Texas_X2QFN-12_1.6x1.6mm_P0.4mm_noSilk
U6: TPS61023DRLR; SOT-563_noSilk
U7: BQ24074RGT; BQ24074_QFN-16_3x3mm_withThermalVia_noSilk

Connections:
+3V3: Brd2.7 (VCC), C1.2, C11.2, C12.2, C13.1, C14.1, R1.2, R6.2, R15.1, R16.1, R17.1, R18.1, R25.2, R26.2, RV1.3, RV2.3, RV3.3, U1.3 (3V3), U4.2 (VO), U5.12 (VDD), U7.6 (EN1)
+5V: C2.1, C4.1, C6.1, C7.1, C8.1, C9.1, C10.1, R9.1, R10.2, R13.1, U3.1 (VIN), U4.1 (VI), U6.6 (VOUT)
BAT_VSENSE: C27.1, R28.2, U1.21 (IO17)
BAT_VSENSE_RAW: R27.2, R28.1, R29.2
BOOT: R6.1, SW6.1 (A), U1.4 (IO0)
CHG: R25.1, SW1.6 (C), U1.30 (IO48), U7.9 (~CHG)
D+: L1.2, U1.24 (USB_D+)
D-: L1.3, U1.23 (USB_D-)
FLASH_RX: R8.1, U1.40 (RXD0)
FLASH_TX: R7.2, U1.39 (TXD0)
Frt0: D1_0.1 (K), D2_0.1 (K), D3_0.1 (K), D4_0.1 (K), D5_0.1 (K), D6_0.1 (K), U1.44 (IO46)
Frt1: D1_1.1 (K), D2_1.1 (K), D3_1.1 (K), D4_1.1 (K), D5_1.1 (K), D6_1.1 (K), U1.41 (IO45)
Frt2: D1_2.1 (K), D2_2.1 (K), D3_2.1 (K), D4_2.1 (K), D5_2.1 (K), D6_2.1 (K), U1.31 (IO35)
Frt3: D1_3.1 (K), D2_3.1 (K), D3_3.1 (K), D4_3.1 (K), D5_3.1 (K), D6_3.1 (K), U1.32 (IO36)
Frt4: D1_4.1 (K), D2_4.1 (K), D3_4.1 (K), D4_4.1 (K), D5_4.1 (K), D6_4.1 (K), U1.33 (IO37)
Frt5: D1_5.1 (K), D2_5.1 (K), D3_5.1 (K), D4_5.1 (K), D5_5.1 (K), D6_5.1 (K), U1.29 (IO34)
Frt6: D1_6.1 (K), D2_6.1 (K), D3_6.1 (K), D4_6.1 (K), D5_6.1 (K), D6_6.1 (K), U1.28 (IO33)
Frt7: D1_7.1 (K), D2_7.1 (K), D3_7.1 (K), D4_7.1 (K), D5_7.1 (K), D6_7.1 (K), U1.27 (IO47)
Frt8: D1_8.1 (K), D2_8.1 (K), D3_8.1 (K), D4_8.1 (K), D5_8.1 (K), D6_8.1 (K), U1.25 (IO21)
Frt9: D1_9.1 (K), D2_9.1 (K), D3_9.1 (K), D4_9.1 (K), D5_9.1 (K), D6_9.1 (K), U1.19 (IO15)
Frt10: D1_10.1 (K), D2_10.1 (K), D3_10.1 (K), D4_10.1 (K), D5_10.1 (K), D6_10.1 (K), U1.18 (IO14)
Frt11: D1_11.1 (K), D2_11.1 (K), D3_11.1 (K), D4_11.1 (K), D5_11.1 (K), D6_11.1 (K), U1.17 (IO13)
Frt12: D1_12.1 (K), D2_12.1 (K), D3_12.1 (K), D4_12.1 (K), D5_12.1 (K), D6_12.1 (K), U1.16 (IO12)
GNDA: C15.2, C16.2, C17.2, C18.2, C19.2, C20.2, C21.2, C22.2, C23.2, C24.2, C25.2, C26.2, C27.2, J4.2, NT2.2, R22.1, R23.1, R24.1, R29.1, RV1.1, RV2.1, RV3.1, SW2.1 (A), SW3.1 (A), SW4.1 (A), TH1.2, U7.4 (~CE), U7.5 (EN2), U7.8 (VSS), U7.14 (TMR), U7.17 (VSS)
GNDD: Brd2.6 (GND), C1.1, C2.2, C3.2, C4.2, C5.2, C6.2, C7.2, C8.2, C9.2, C11.1, C12.1, C13.2, C14.2, C28.2, C29.2, C30.2, C31.1, D1.2 (A2), J1.A1 (GND), J1.A12 (GND), J1.B1 (GND), J1.B12 (GND), J1.S1 (SHIELD), J2.A1 (GND), J2.A12 (GND), J2.B1 (GND), J2.B12 (GND), J2.S1 (SHIELD), J3.S, NT2.1, Q1.2 (E), R2.2, R3.2, R12.2, R14.1, R30.1, SW5.2 (B), SW6.2 (B), TP1.1, TP4.1, U1.1 (GND), U1.2 (GND), U1.42 (GND), U1.43 (GND), U1.46 (GND), U1.47 (GND), U1.48 (GND), U1.49 (GND), U1.50 (GND), U1.51 (GND), U1.52 (GND), U1.53 (GND), U1.54 (GND), U1.55 (GND), U1.56 (GND), U1.57 (GND), U1.58 (GND), U1.59 (GND), U1.60 (GND), U1.61 (GND), U1.62 (GND), U1.63 (GND), U1.64 (GND), U1.65 (GND), U2.3 (GND), U3.2 (GND), U4.3 (GND), U5.10 (GND), U5.11 (~EN), U6.4 (GND)
LED: SW1.4 (A), U1.10 (IO6)
unnamed: D1.1 (A1), F2.2, J2.A4 (VBUS), J2.A9 (VBUS), J2.B4 (VBUS), J2.B9 (VBUS)
unnamed: D1_0.2 (A), SW1_0.2
unnamed: D1_1.2 (A), SW1_1.2
unnamed: D1_2.2 (A), SW1_2.2
unnamed: D1_3.2 (A), SW1_3.2
unnamed: D1_4.2 (A), SW1_4.2
unnamed: D1_5.2 (A), SW1_5.2
unnamed: D1_6.2 (A), SW1_6.2
unnamed: D1_7.2 (A), SW1_7.2
unnamed: D1_8.2 (A), SW1_8.2
unnamed: D1_9.2 (A), SW1_9.2
unnamed: D1_10.2 (A), SW1_10.2
unnamed: D1_11.2 (A), SW1_11.2
unnamed: D1_12.2 (A), SW1_12.2
unnamed: D2_0.2 (A), SW2_0.2
unnamed: D2_1.2 (A), SW2_1.2
unnamed: D2_2.2 (A), SW2_2.2
unnamed: D2_3.2 (A), SW2_3.2
unnamed: D2_4.2 (A), SW2_4.2
unnamed: D2_5.2 (A), SW2_5.2
unnamed: D2_6.2 (A), SW2_6.2
unnamed: D2_7.2 (A), SW2_7.2
unnamed: D2_8.2 (A), SW2_8.2
unnamed: D2_9.2 (A), SW2_9.2
unnamed: D2_10.2 (A), SW2_10.2
unnamed: D2_11.2 (A), SW2_11.2
unnamed: D2_12.2 (A), SW2_12.2
unnamed: D3.2 (A), R5.1
unnamed: D3.1 (K), SW1.5 (B)
unnamed: D3_0.2 (A), SW3_0.2
unnamed: D3_1.2 (A), SW3_1.2
unnamed: D3_2.2 (A), SW3_2.2
unnamed: D3_3.2 (A), SW3_3.2
unnamed: D3_4.2 (A), SW3_4.2
unnamed: D3_5.2 (A), SW3_5.2
unnamed: D3_6.2 (A), SW3_6.2
unnamed: D3_7.2 (A), SW3_7.2
unnamed: D3_8.2 (A), SW3_8.2
unnamed: D3_9.2 (A), SW3_9.2
unnamed: D3_10.2 (A), SW3_10.2
unnamed: D3_11.2 (A), SW3_11.2
unnamed: D3_12.2 (A), SW3_12.2
unnamed: D4_0.2 (A), SW4_0.2
unnamed: D4_1.2 (A), SW4_1.2
unnamed: D4_2.2 (A), SW4_2.2
unnamed: D4_3.2 (A), SW4_3.2
unnamed: D4_4.2 (A), SW4_4.2
unnamed: D4_5.2 (A), SW4_5.2
unnamed: D4_6.2 (A), SW4_6.2
unnamed: D4_7.2 (A), SW4_7.2
unnamed: D4_8.2 (A), SW4_8.2
unnamed: D4_9.2 (A), SW4_9.2
unnamed: D4_10.2 (A), SW4_10.2
unnamed: D4_11.2 (A), SW4_11.2
unnamed: D4_12.2 (A), SW4_12.2
unnamed: D5_0.2 (A), SW5_0.2
unnamed: D5_1.2 (A), SW5_1.2
unnamed: D5_2.2 (A), SW5_2.2
unnamed: D5_3.2 (A), SW5_3.2
unnamed: D5_4.2 (A), SW5_4.2
unnamed: D5_5.2 (A), SW5_5.2
unnamed: D5_6.2 (A), SW5_6.2
unnamed: D5_7.2 (A), SW5_7.2
unnamed: D5_8.2 (A), SW5_8.2
unnamed: D5_9.2 (A), SW5_9.2
unnamed: D5_10.2 (A), SW5_10.2
unnamed: D5_11.2 (A), SW5_11.2
unnamed: D5_12.2 (A), SW5_12.2
unnamed: D6_0.2 (A), SW6_0.2
unnamed: D6_1.2 (A), SW6_1.2
unnamed: D6_2.2 (A), SW6_2.2
unnamed: D6_3.2 (A), SW6_3.2
unnamed: D6_4.2 (A), SW6_4.2
unnamed: D6_5.2 (A), SW6_5.2
unnamed: D6_6.2 (A), SW6_6.2
unnamed: D6_7.2 (A), SW6_7.2
unnamed: D6_8.2 (A), SW6_8.2
unnamed: D6_9.2 (A), SW6_9.2
unnamed: D6_10.2 (A), SW6_10.2
unnamed: D6_11.2 (A), SW6_11.2
unnamed: D6_12.2 (A), SW6_12.2
unnamed: F1.1, FB2.2
unnamed: F1.2, J1.A4 (VBUS), J1.A9 (VBUS), J1.B4 (VBUS), J1.B9 (VBUS)
unnamed: F2.1, FB1.2
unnamed: J1.A5 (CC1), R2.1
unnamed: J1.B5 (CC2), R3.1
unnamed: J3.T, R9.2
unnamed: C26.1, J4.1, R27.1, U7.2 (BAT), U7.3 (BAT)
unnamed: Q1.1 (B), R4.2, R30.2
unnamed: J3.R, Q1.3 (C)
unnamed: R19.1, RV1.2
unnamed: R20.1, RV2.2
unnamed: R21.1, RV3.2
unnamed: C31.2, R1.1, SW5.1 (A), U1.45 (EN)
unnamed: SW7.1 (A), TP3.1
unnamed: R7.1, SW7.2 (B)
unnamed: SW8.1 (A), TP5.1
unnamed: R8.2, SW8.2 (B)
unnamed: R10.1, U3.3 (~CE)
unnamed: R12.1, U5.5 (ADDR)
unnamed: R16.2, U5.9 (ID)
unnamed: C5.1, R11.1, U5.4 (VBUS_DET)
unnamed: R15.2, U5.6 (~INT/OUT3)
unnamed: C10.2, R13.2, R14.2, U6.1 (FB)
unnamed: L2.2, U6.5 (SW)
unnamed: R22.2, U7.12 (ILIM)
unnamed: R24.2, U7.16 (ISET)
unnamed: R23.2, U7.15 (ITERM)
unnamed: TH1.1, U7.1 (TS)
PGOOD: R26.1, U1.34 (IO38), U7.7 (~PGOOD)
SCL: Brd2.4 (CLK), R17.2, U1.20 (IO16), U5.8 (SCL/OUT2)
SDA: Brd2.5 (DIN), R18.2, U1.22 (IO18), U5.7 (SDA/OUT1)
SLDR1: C15.1, R19.2, U1.8 (IO4)
SLDR2: C16.1, R20.2, U1.6 (IO2)
SLDR3: C17.1, R21.2, U1.5 (IO1)
SW_CENTER: C18.1, SW2.2 (B), U1.36 (IO40)
SW_LEFT: C20.1, SW4.2 (B), SW8.3 (C)
SW_RIGHT: C19.1, SW3.2 (B), U1.35 (IO39)
SYS: C23.1, C24.1, C25.1, R5.2, SW1.2 (B), U7.10 (OUT), U7.11 (OUT)
SYS_SW: C28.1, C29.1, C30.1, L2.1, SW1.3 (C), U6.2 (EN), U6.3 (VIN)
Str1: SW1_0.1, SW1_1.1, SW1_2.1, SW1_3.1, SW1_4.1, SW1_5.1, SW1_6.1, SW1_7.1, SW1_8.1, SW1_9.1, SW1_10.1, SW1_11.1, SW1_12.1, U1.9 (IO5)
Str2: SW2_0.1, SW2_1.1, SW2_2.1, SW2_3.1, SW2_4.1, SW2_5.1, SW2_6.1, SW2_7.1, SW2_8.1, SW2_9.1, SW2_10.1, SW2_11.1, SW2_12.1, U1.11 (IO7)
Str3: SW3_0.1, SW3_1.1, SW3_2.1, SW3_3.1, SW3_4.1, SW3_5.1, SW3_6.1, SW3_7.1, SW3_8.1, SW3_9.1, SW3_10.1, SW3_11.1, SW3_12.1, U1.12 (IO8)
Str4: SW4_0.1, SW4_1.1, SW4_2.1, SW4_3.1, SW4_4.1, SW4_5.1, SW4_6.1, SW4_7.1, SW4_8.1, SW4_9.1, SW4_10.1, SW4_11.1, SW4_12.1, U1.13 (IO9)
Str5: SW5_0.1, SW5_1.1, SW5_2.1, SW5_3.1, SW5_4.1, SW5_5.1, SW5_6.1, SW5_7.1, SW5_8.1, SW5_9.1, SW5_10.1, SW5_11.1, SW5_12.1, U1.15 (IO11)
Str6: SW6_0.1, SW6_1.1, SW6_2.1, SW6_3.1, SW6_4.1, SW6_5.1, SW6_6.1, SW6_7.1, SW6_8.1, SW6_9.1, SW6_10.1, SW6_11.1, SW6_12.1, U1.14 (IO10)
TXD: R4.1, SW7.3 (C)
USB1_VBUS: C21.1, C22.1, FB2.1, U7.13 (IN)
USB2_CC1: J2.A5 (CC1), U5.1 (CC1)
USB2_CC2: J2.B5 (CC2), U5.2 (CC2)
USB2_D+: J2.A6 (D+), L1.1, U2.1 (D+)
USB2_D-: J2.A7 (D-), L1.4, U2.2 (D-)
VBUS2: C3.1, FB1.1, R11.2, U3.6 (VOUT)

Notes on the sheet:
安定3.3V
USB2 保護
コモンドチョーク
理想ダイオード／逆流防止スイッチ
ESD保護素子(USB端子から最短)
FLAS用UART確保
昇圧型DC/DCコンバータ
USBのCCライン制御
安定5V
バッテリー充電管理と電源の切り替え
同じ長さにする
TRS MIDI TypeA 信号線を要確認
Analog GND
電源トグル/充電監視LED
右側インターフェイス
データ/電源両用USB USB2
3.3 V 低ドロップアウトレギュレータ（LDO）
電源供給専用USB USB1
左側インターフェイス

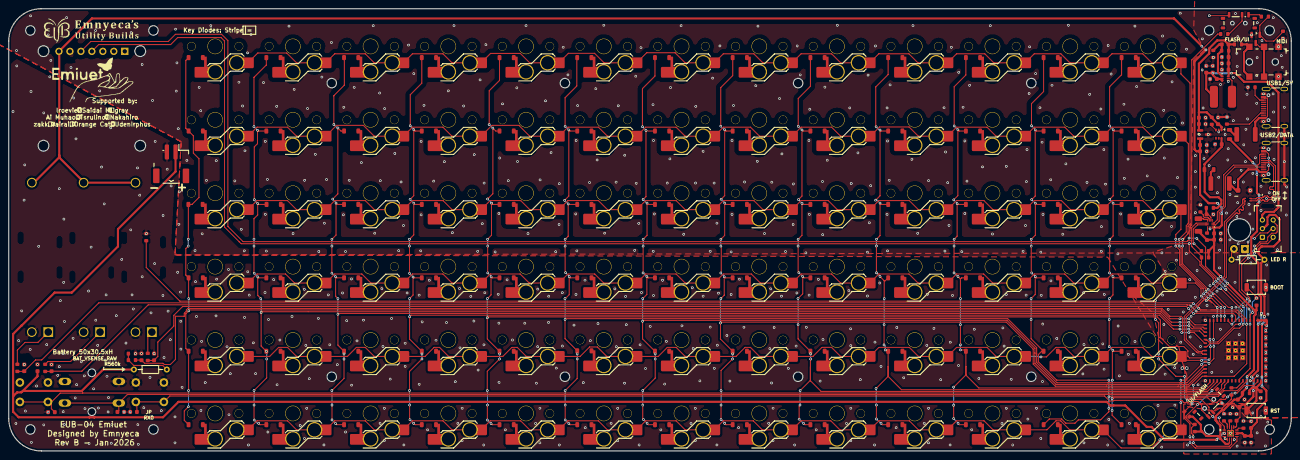
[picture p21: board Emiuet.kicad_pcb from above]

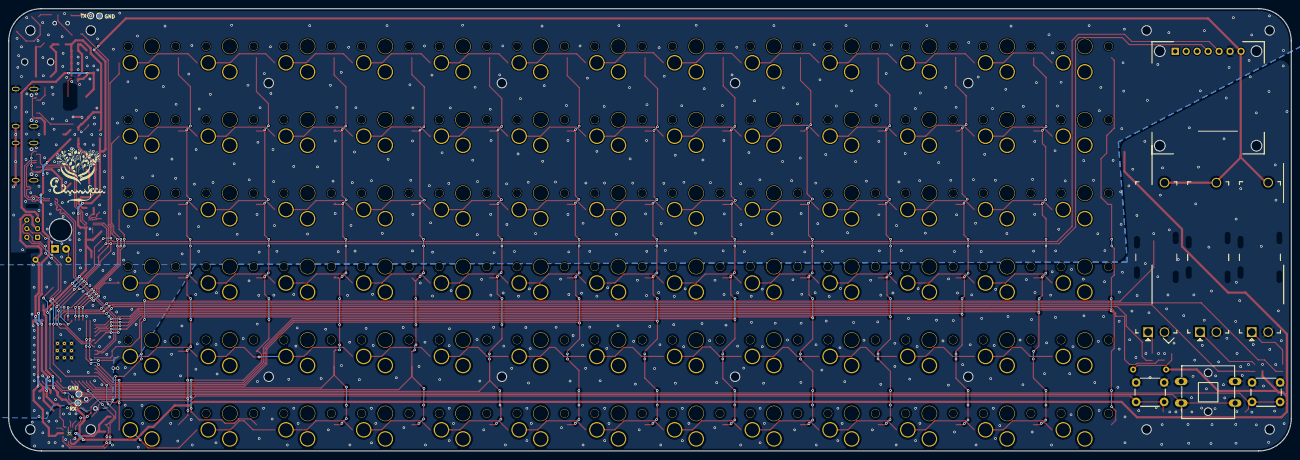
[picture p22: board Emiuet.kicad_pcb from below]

Board: 2 copper layers, 297.0 x 102.4 mm, 272 parts (13 on the bottom side), 159 nets.

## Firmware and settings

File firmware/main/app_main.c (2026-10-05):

#include <stdio.h>

#include "freertos/FreeRTOS.h"
#include "freertos/task.h"

#include "board_pins.h"
#include "board_i2c.h"
#include "led_renderer.h"
#include "usb_cc_detect.h"
#include "ui_led_status.h"
#include "ui_oled.h"

#include "controls.h"

#include "matrix_midi_bridge.h"
#include "slider.h"

static void board_late_init_task(void *arg)
{
    (void)arg;


    /* Strapping safety delay */
    vTaskDelay(pdMS_TO_TICKS(MATRIX_SCAN_START_DELAY_MS));

    /* Stage 1: configure rows only to avoid touching strapping pins */
    board_pins_init_matrix_prepare();

    /* Short pause before enabling column inputs */
    vTaskDelay(pdMS_TO_TICKS(50));

    /* Stage 2: enable column inputs (now safe) */
    board_pins_enable_matrix_columns();

    /* Start matrix -> mode router with initial discard cycles to avoid
     * reacting to boot-time strapping states or keys held during boot.
     */
    matrix_midi_bridge_start(MATRIX_INITIAL_DISCARD_CYCLES);
    /* Start slider polling task (pitch-bend) */
    slider_task_start();

    /* One-shot task */
    vTaskDelete(NULL);
}

void app_main(void)
{
    printf("Emiuet firmware: boot\n");

    /* Stage 1: safe pins only (LED/buttons/power status, etc.) */
    board_pins_init_early();

    /* Rev.B: I2C serves the OLED; USB-C current is a CC comparator GPIO. */
    (void)board_i2c_init();
    (void)usb_cc_detect_start();
    (void)led_renderer_start();

    /* Centralized buttons + control state machine (octave/MPE/long-press) */
    controls_start();

    printf("Emiuet firmware: starting demo tasks\n");
    led_status_start();
    oled_demo_start();

    /* Stage 2: matrix pins after boot delay (strapping pins safety) */
    xTaskCreate(board_late_init_task, "board_late_init", 8192, NULL, 5, NULL);

    // app_main can return; tasks keep running.
}

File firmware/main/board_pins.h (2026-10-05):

#pragma once

/* Implementation of the Rev.B GPIO allocation in docs/pinout-v3.md.
 * Keep GPIO0/3/45/46 free of normal loads because they are strapping pins.
 * GPIO19/20 are dedicated to native USB. GPIO26 is unavailable on N4R2.
 */

#include <stdint.h>
#include <stdbool.h>
#include "driver/gpio.h"

#define PIN_USB_D_MINUS       GPIO_NUM_19
#define PIN_USB_D_PLUS        GPIO_NUM_20

#define PIN_I2C_SDA           GPIO_NUM_39
#define PIN_I2C_SCL           GPIO_NUM_40
#define PIN_USB_CC_1A5_N      GPIO_NUM_37

#define PIN_MIDI_OUT_TX       GPIO_NUM_43
#define PIN_MIDI_IN_RX        GPIO_NUM_44

#define PIN_RGB_DATA          GPIO_NUM_38
#define PIN_STATUS_LED        GPIO_NUM_48

#define PIN_SLIDER_PB         GPIO_NUM_1
#define PIN_SLIDER_MOD        GPIO_NUM_2
#define PIN_SLIDER_VEL        GPIO_NUM_4

#define PIN_SW_CENTER         GPIO_NUM_41
#define PIN_SW_RIGHT          GPIO_NUM_42
#define PIN_SW_LEFT           GPIO_NUM_47

#define MATRIX_NUM_ROWS 6
#define MATRIX_NUM_COLS 13

extern const gpio_num_t MATRIX_ROW_PINS[MATRIX_NUM_ROWS];
extern const gpio_num_t MATRIX_COL_PINS[MATRIX_NUM_COLS];

/* No matrix signal is on a strapping pin in Rev.B. The short delay still lets
 * USB power and peripherals settle before the 78-key scanner starts.
 */
#define MATRIX_SCAN_START_DELAY_MS 100
#define IS_STRAPPING_COL(col_index) (false)

void board_pins_init_early(void);
void board_pins_init_matrix_prepare(void);
void board_pins_enable_matrix_columns(void);
void board_pins_init_matrix_late(void);

#ifndef MATRIX_INITIAL_DISCARD_CYCLES
#define MATRIX_INITIAL_DISCARD_CYCLES 5
#endif

#ifndef MATRIX_ROW_INTERNAL_PULLUP
#define MATRIX_ROW_INTERNAL_PULLUP 1
#endif

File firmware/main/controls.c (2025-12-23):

#include "controls.h"

#include "board_pins.h"
#include "driver/gpio.h"
#include "esp_log.h"
#include "esp_timer.h"
#include "freertos/FreeRTOS.h"
#include "freertos/task.h"

#include "midi_mpe.h"

static const char *TAG = "controls";

#ifndef CONTROLS_POLL_MS
#define CONTROLS_POLL_MS 10
#endif

/* Debounce: accept a change only after it is stable this long. */
#ifndef CONTROLS_DEBOUNCE_US
#define CONTROLS_DEBOUNCE_US 30000
#endif

/* Long-press threshold for SW_CENTER. */
#ifndef CONTROLS_CENTER_LONGPRESS_US
#define CONTROLS_CENTER_LONGPRESS_US 800000
#endif

typedef struct {
    int raw_level;               /* last sampled level */
    int stable_level;            /* debounced stable level */
    int64_t last_raw_change_us;  /* timestamp of last raw change */

    /* Press tracking for actions */
    bool pressed;                /* stable pressed state */
    int64_t press_start_us;      /* when stable press began */
    bool long_fired;             /* long press already fired */
} button_state_t;

static TaskHandle_t s_task = NULL;
static int8_t s_octave = 0;

/* Stub hook: implement this symbol elsewhere when BLE pairing is real. */
__attribute__((weak)) void emiuet_ble_pairing_request(void)
{
    ESP_LOGW(TAG, "BLE pairing requested (stub)");
}

static inline int clamp_i8(int v, int lo, int hi)
{
    if (v < lo) return lo;
    if (v > hi) return hi;
    return v;
}

static void button_init(button_state_t *b)
{
    int level = 1;
    b->raw_level = level;
    b->stable_level = level;
    b->last_raw_change_us = esp_timer_get_time();
    b->pressed = false;
    b->press_start_us = 0;
    b->long_fired = false;
}

static bool button_update(button_state_t *b, gpio_num_t pin, int64_t now_us)
{
    int level = gpio_get_level(pin);
    if (level != b->raw_level) {
        b->raw_level = level;
        b->last_raw_change_us = now_us;
    }

    if (b->stable_level != b->raw_level) {
        if ((now_us - b->last_raw_change_us) >= CONTROLS_DEBOUNCE_US) {
            b->stable_level = b->raw_level;
            return true; /* stable edge */
        }
    }

    return false;
}

static inline bool is_pressed_level(int stable_level)
{
    /* Active-low buttons */
    return stable_level == 0;
}

static void controls_task(void *arg)
{
    (void)arg;

    TickType_t delay_ticks = pdMS_TO_TICKS(CONTROLS_POLL_MS);
    if (delay_ticks < 1) delay_ticks = 1;

    button_state_t b_center;
    button_state_t b_left;
    button_state_t b_right;

    button_init(&b_center);
    button_init(&b_left);
    button_init(&b_right);

    /* Seed initial stable levels from pins (after board_pins_init_early). */
    int64_t now_us = esp_timer_get_time();
    b_center.raw_level = b_center.stable_level = gpio_get_level(PIN_SW_CENTER);
    b_left.raw_level = b_left.stable_level = gpio_get_level(PIN_SW_LEFT);
    b_right.raw_level = b_right.stable_level = gpio_get_level(PIN_SW_RIGHT);
    b_center.last_raw_change_us = b_left.last_raw_change_us = b_right.last_raw_change_us = now_us;

    while (1) {
        now_us = esp_timer_get_time();

        (void)button_update(&b_center, PIN_SW_CENTER, now_us);
        bool left_edge = button_update(&b_left, PIN_SW_LEFT, now_us);
        bool right_edge = button_update(&b_right, PIN_SW_RIGHT, now_us);

        /* LEFT/RIGHT: octave step on stable press (falling edge). */
        if (left_edge && is_pressed_level(b_left.stable_level)) {
            s_octave = (int8_t)clamp_i8((int)s_octave - 1, -3, 3);
            ESP_LOGI(TAG, "octave=%d", (int)s_octave);
        }
        if (right_edge && is_pressed_level(b_right.stable_level)) {
            s_octave = (int8_t)clamp_i8((int)s_octave + 1, -3, 3);
            ESP_LOGI(TAG, "octave=%d", (int)s_octave);
        }

        /* CENTER: short press toggles MPE, long press triggers BLE pairing hook.
         * Long press suppresses the short action on release.
         */
        bool center_pressed = is_pressed_level(b_center.stable_level);
        if (center_pressed && !b_center.pressed) {
            b_center.pressed = true;
            b_center.press_start_us = now_us;
            b_center.long_fired = false;
        } else if (!center_pressed && b_center.pressed) {
            /* release */
            b_center.pressed = false;
            if (!b_center.long_fired) {
                bool new_en = !midi_mpe_is_enabled();
                midi_mpe_set_enabled(new_en);
                ESP_LOGI(TAG, "SW_CENTER short: MPE %s", new_en ? "ENABLED" : "DISABLED");
            }
        } else if (center_pressed && b_center.pressed && !b_center.long_fired) {
            if ((now_us - b_center.press_start_us) >= CONTROLS_CENTER_LONGPRESS_US) {
                b_center.long_fired = true;
                ESP_LOGI(TAG, "SW_CENTER long: BLE pairing request");
                emiuet_ble_pairing_request();
            }
        }

        vTaskDelay(delay_ticks);
    }
}

void controls_start(void)
{
    if (s_task) return;

    /* Pins are configured in board_pins_init_early(). */
    xTaskCreate(controls_task, "controls", 4096, NULL, 6, &s_task);
}

int8_t controls_get_octave(void)
{
    return s_octave;
}

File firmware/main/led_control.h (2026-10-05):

#pragma once

#include <stdbool.h>
#include <stdint.h>

#define EMUIET_LED_ROWS 6
#define EMUIET_LED_COLS 13
#define EMUIET_LED_COUNT (EMUIET_LED_ROWS * EMUIET_LED_COLS)

typedef struct { uint8_t red, green, blue; } led_rgb_t;

typedef enum {
    LED_DISPLAY_NOTES = 0,
    LED_DISPLAY_OFF,
} led_display_mode_t;

void led_control_init(void);
void led_control_handle_midi(uint8_t status, uint8_t data1, uint8_t data2);
void led_control_set_global_brightness(uint8_t brightness);
void led_control_set_display_mode(led_display_mode_t mode);
uint32_t led_control_snapshot(led_rgb_t pixels[EMUIET_LED_COUNT], uint8_t *brightness);
uint16_t led_layout_physical_index(uint8_t row, uint8_t col);

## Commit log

2025-12-18 Add hardware project structure
    [Emiuet.kicad_sch, Emiuet_RevA_BOM.xlsx, Emiuet_plate.kicad_pcb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]
2025-12-18 Add gitignore for KiCad and ESP-IDF
2025-12-18 Fix broken submodule state and stabilize unified repository
    [led_status.c, oled_demo.c]
2025-12-18 include u8g2
    [board.dxf, clock.dxf, clock_2.dxf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]
2025-12-20 Stabilize board_pins and boot sequence
    - Fix GPIO assignments and late init
    - Restore boot animation and OLED init
    - Confirm stable boot without reboot loop
    [app_main.c, board_pins.c, board_pins.h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]
2025-12-21 firmware: add non-blocking matrix scanner, MIDI bridge, slider ADC & pitch-bend task, MPE support
    - Add non-blocking matrix_scan (debounce + callback)\n- Add matrix_midi_bridge to convert key events to NoteOn/Off and integrate with MPE\n- Provide midi_out stubs and midi_mpe implementation for per-string pitch-bend routing\n- Implement slider ADC using esp_adc oneshot API and EMA filtering\n- Add slider_task to poll pitch-bend and emit upward-only 14-bit MIDI pitch bends\n- Start matrix and slider tasks from app_main; update CMakeLists to include slider task\n- Minor fixes: esp_rom_delay_us declaration compatibility and build tweaks
    [app_main.c, matrix_scan.c, midi_out.c]
2025-12-21 firmware: staged matrix init + robust debounce + boot-safety discard\n\n- Add stable_pressed and transition-only debounce in matrix_scan\n- Add discard_cycles support to ignore early scans (protect s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
    [app_main.c, board_pins.c, board_pins.h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]
2025-12-21 firmware: safety fixes for matrix init and debounce
    - Skip counter updates during initial discard and capture current physical state at discard end\n- Transition-only stable_pressed debounce to avoid repeated NoteOn/Off\n- Split matrix init into prepare/enable and add configurable internal pull-ups for columns\n- Remove externs from app_main and use headers\n- Updated MATRIX_INITIAL_DISCARD_CYCLES default to safer value
    [app_main.c, board_pins.c, board_pins.h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]
2025-12-21 slider: add enabled flag and slider_is_enabled(); prevent starting slider task when ADC not configured
    [slider.c]
2025-12-21 Pitch bend utilization especially for reset attributes
2025-12-21 slider: stabilize ADC reads and state-machine sending; robust ADC failure handling
    [app_main.c, board_pins.h, oled_demo.c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]
2025-12-21 matrix: per-string simulator; sim/hw state split; thread-safe matrix state; oled/midi use sim; increase sim task stacks
2025-12-22 Centralize ADC access via adc_manager
    Use adc_manager in slider/OLED to eliminate ADC oneshot unit conflicts.
    Gate USB-MIDI backend on CONFIG_TINYUSB_MIDI_COUNT and keep esp_tinyusb dependency files.
2025-12-22 MPE: base..base+5 clamp; gate simulator default
2025-12-22 Rename OLED/LED UI modules
    oled_demo -> ui_oled; led_status -> ui_led_status (API unchanged)
2025-12-22 TRS MIDI: UART31250 backend
    Add Kconfig gate, UART0 console guard, and drop-rate logging
2025-12-22 MIDI: TRS/USB stability tuning; BLE init fix
    - BLE: init returns success; stub send avoids noisy drop stats
    - USB: default discrete queue len 1024; keep HWM/drop stats
    - TRS: remove mutex; sender task owns UART; uart_driver_install rx/tx buffers
    - Docs: document TRS>USB=BLE priority and PB/CC1 coalescing
    [midi_out.c, midi_out_uart_trs.c]
2026-01-09 Fix Kicad Data
    [Emiuet.kicad_pcb, Emiuet.kicad_sch, Emiuet_plate.kicad_pcb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]
2026-01-09 KiCad REV-B Design
    [Emiuet.kicad_pcb, Emiuet.kicad_sch]
2026-01-16 DEV-Aでテストしながら基板の改良
    [Emiuet.kicad_sch, Emiuet_topRight.kicad_pcb]
2026-01-16 save漏れ
    [Emiuet.kicad_pcb]
2026-01-18 ロゴ追加
2026-01-19 キーマトリックスのスキャンを基板実装と整合
2026-01-19 一時ファイルを削除
2026-01-25 BOOTスイッチ修正
    [Emiuet.kicad_pcb, Emiuet.kicad_sch]
2026-08-26 スタンドアローンのMIDI楽器であることを明確化
2026-08-31 キーボード入力機能の実装
2026-08-31 Rev.BをUSB Device-only方針へ移行
2026-09-01 Rev.BをUSB給電RGB構成へ更新
    - 単一USB-C Device/UFP給電へ回路方針を変更（内蔵電池・充電・PowerPath・boost・Host VBUS経路を撤去）
    - TUSB320を固定UFPとしI2C status読出しのみに限定
    - SK6812 MINI-E x78のRGB chain、AHCT level shift、RMT/DMA rendererを追加
    - USB MIDI + HID Keyboard composite、TRS MIDI IN/OUTを整理
    - firmware: led_control/led_renderer/midi_input/usb_power/tusb320/board_i2c を追加
    - KiCad: Rev.A schematicをEmiuet_RevA.kicad_schへ退避し、Rev.B初期schematicたたき台を追加
    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
    [Emiuet.kicad_sch, Emiuet_RevA.kicad_sch]
2026-09-01 レビュー指摘に沿って製品思想と文書構造を復元
2026-10-05 Rev.BのCC検出と送信taskを整備しレビュー指摘を修正
    [Emiuet.kicad_sch]
2026-10-05 Rev.B電源候補と入力保護の選定条件を整理
2026-10-05 検証用基板の設計と発注責務を明確化
2026-10-05 発注前のオーナー確認を段階化
